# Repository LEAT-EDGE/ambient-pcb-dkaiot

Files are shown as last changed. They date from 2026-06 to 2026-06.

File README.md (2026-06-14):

# Ambient DKAIoT Mainboard PCB

Mainboard PCB for the [Ambient project](https://github.com/LEAT-EDGE/ambient).

<div style="display: flex; justify-content: center; gap: 20px;">
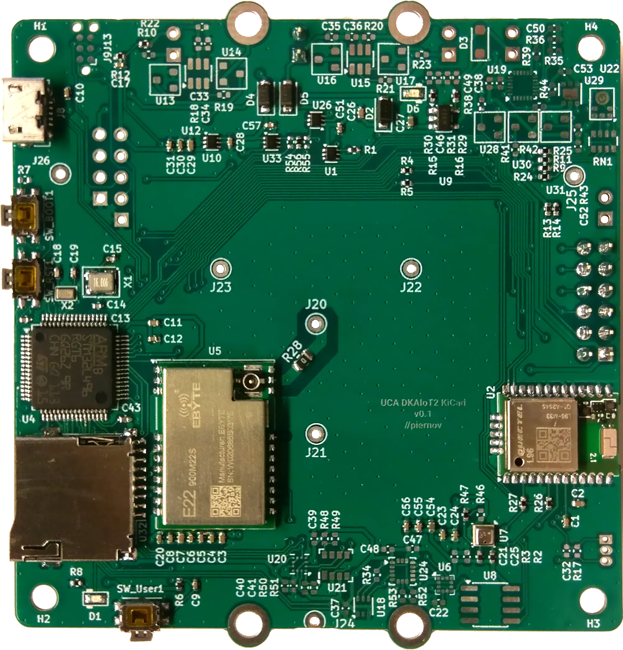
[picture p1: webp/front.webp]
Mainboard front
    
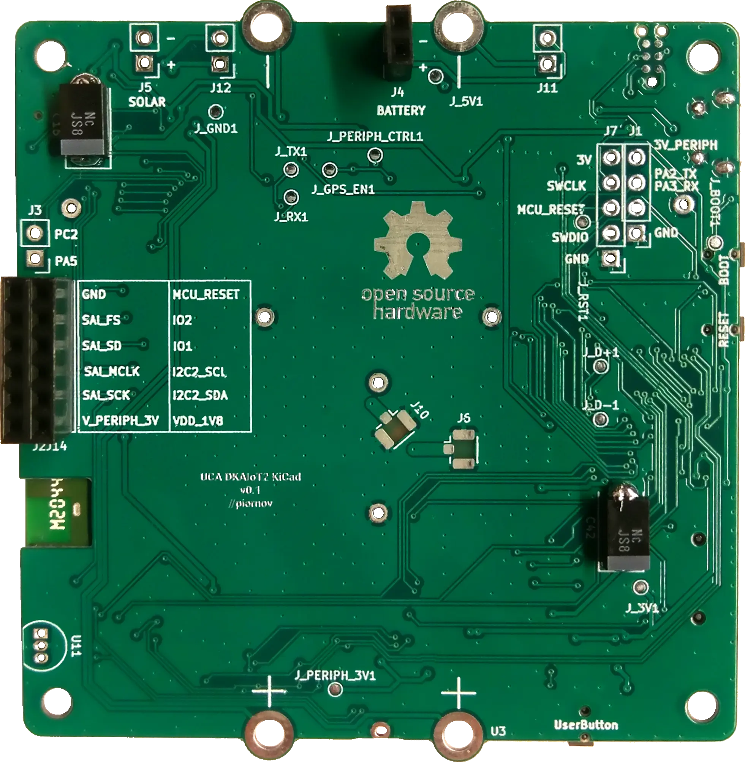
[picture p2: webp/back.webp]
Mainboard back
    
</div>

## Main features

- Microcontroller from the STM32L4 or STM32U5 families (LQFP-64 package, no SMPS)
  - STM32L496RG: low-power, Cortex-M4F 80 MHz, 320 KiB SRAM, 1 MiB Flash
  - STM32U595RI: ultra-low-power, Cortex-M33 160 MHz, 2.5 MiB SRAM, 2 MiB Flash
- LoRa modem (Ebyte E22-900M22S)
- GNSS module (Quectel L96-M33)
- Temperature, humidity and pressure (Bosch BME280)
- Micro-SD card reader

The design also provides empty footprints for several other sensors which are not populated in the Ambient variant:
- Light sensor (LITEON LTR-303ALS-01)
- MEMS microphone (Knowles SPH0645LM4H)
- Indoor air quality (Sensirion SGP30)
- Hall effect (Texas Instruments DRV5023AJQLPG)
- Barometer and altimeter (HopeRF HP203B)
- 3-axis accelerometer, 3-axis gyroscope, 3-axis magnetometer (TDK ICM-20948)
- 3-axis accelerometer, 3-axis magnetometer (STMicroelectronics LSM303AH)
- 3-axis accelerometer (Kionix KX023-1025-FR)
- 3-axis accelerometer (Kionix KXTJ3-1057)

## Project structure
- `/` (repository root): KiCad project
- `gerbers/`: Gerbers generated from the KiCad project
- `libraries/`: KiCad libraries of symbols, footprints and 3D models for components not found in the KiCad official repository
- `pdf/`: Schematics generated from the KiCad project
- `png/`: Screenshots of the KiCad 3D render
- `webp/`: Pictures of the actual board

## Firmware

### Firmware sources

Refer to <https://github.com/LEAT-EDGE/ambient-firmware-zephyr> for the new, Zephyr RTOS-based firmware (compatible with both STM32L4 and STM32U5),
and to <https://github.com/LEAT-EDGE/ambient-firmware-arduino> for the old Arduino-based firmware (not compatible with STM32U5).

### Updating the firmware

In order to flash the firmware, put the microcontroller in bootloader DFU mode by holding the BOOT button (right next to the USB port) and pressing the RESET button (next to the BOOT button), then releasing the BOOT button after a couple of seconds. Alternatively, you can hold the BOOT button while plugging the USB cable in, and releasing it after a couple of seconds.

[dfu-util](https://dfu-util.sourceforge.net/) can then be used to update the firmware.
It is called automatically by the `west flash` command when using the Zephyr-based firmware, or by the Arduino IDE's Upload button when using the Arduino-based firmware.

On Windows, for `dfu-util` to work properly, it is recommended to use the WinUSB driver. [Zadig](https://zadig.akeo.ie/) can be used to change the driver of the `STM32 BOOTLOADER` device to WinUSB.

On Linux, for a standard user to have access to the USB device, you may have to install a [udev rules file](https://github.com/LEAT-EDGE/ambient-firmware-arduino/blob/master/stm32dfu.udev.rules) in `/etc/udev/rules.d/`.

An SWD probe (e.g., STLINK V2 or V3) can also be used through the J7 debug header. Programming and debugging can then be performed using [OpenOCD](https://openocd.org/)

## Connectors and headers

### J1: UART

Exposes the `PA2` and `PA3` pins for the `USART2` peripheral of the microcontroller for debugging purposes.

Pinout:

| Pin | Net |
|---|---|
| **4** | `V_PERIPH_3V` |
| **3** | `PA2_TX` |
| **2** | `PA3_RX` |
| **1** | `GND` |

### J2J14

Main connector for the [audio capture and energy management daughterboard](https://github.com/LEAT-EDGE/ambient-pcb-audiopower).

Exposes the I2S bus (`SAI1B`), an I2C bus (`I2C2`), the 1.8V (`VDD_1V8`) and 3.0V (`V_PERIPH_3V`) peripheral supplies, 2 GPIOs (`PA10`, `PA15`) and the microcontroller reset signal (`MCU_RESET`, for reed switch reset trigger).

Pinout:

| Pin | Net | Pin | Net |
|---|---|---|---|
| **11** | `GND` | **12** | `MCU_RESET` |
| **9**  | `SAI_FS` | **10** | `EXT_MIC_IO_2` |
| **7**  | `SAI_SD` | **8**  | `EXT_MIC_IO_2` |
| **5**  | `SAI_MCLK` | **6**  | `I2C2_SCL` |
| **3**  | `SAI_SCK` | **4**  | `I2C2_SDA` |
| **1**  | `V_PERIPH_3V` | **2**  | `VDD_1V8` |

### J3: ADC/DAC

Unused in the Ambient variant.

Exposes 2 GPIOs (`PA5`, `PC2`) that provides access to the microcontroller's ADC and DAC channels.

Pinout:

| Pin | Net |
|---|---|
| **2** | `PC2_ADC` |
| **1** | `PA5_DAC_ADC` |

### J4: BATTERY

Power input to the board and output of the USB charging circuit.

The [audio capture and energy management daughterboard](https://github.com/LEAT-EDGE/ambient-pcb-audiopower) connects to this header with its J3 connector.

| Pin | Net |
|---|---|
| **2** | `+BATT` |
| **1** | `GND` |

### J5: SOLAR

Unused in the Ambient variant.

Power input to the charging circuit

Pinout:

| Pin | Net |
|---|---|
| **2** | `SOLAR` |
| **1** | `GND` |

### J7: SWD

Exposes the SWD pins of the microcontroller for debugging purposes.

Pinout:

| Pin | Net |
|---|---|
| **5** | `3V` |
| **4** | `SWCLK` |
| **3** | `MCU_RESET` |
| **2** | `SWDIO` |
| **1** | `GND` |

### J11: BATT1

Unused in the Ambient variant.

1st Li-ion cell connector, behind protection circuit.

| Pin | Net |
|---|---|
| **2** | `+BATT1_IN` |
| **1** | `-BATT1_IN` |

### J12: BATT2

Unused in the Ambient variant.

2nd Li-ion cell connector, behind protection circuit.

| Pin | Net |
|---|---|
| **2** | `+BATT2_IN` |
| **1** | `-BATT2_IN` |

### J20/J21/J22/J23: antenna header

Used to attach the [LoRa antenna mezzanine PCB](https://github.com/LEAT-EDGE/ambient-pcb-antenna).

| Pin | Net |
|---|---|
| **J20** | `E22_ANT` |
| **J21** | `GND` |
| **J22** | `GND` |
| **J23** | `GND` |

## Fabrication notes

### PCB

Standard 2-layer 0.8mm stackup:
- 2 layers (front/back),
- 0.8mm thickness,
- 1oz copper,
- FR-4 dielectric,
- HASL finish.

No special requirements, any solder mask and silkscreen color.

Gerbers are provided in the `gerbers/` directory but can be re-generated from the KiCad project.

### Assembly

Recommended automated assembly for top-side only.

Manual assembly for top side:
- J20, J21, J22 and J23 pins (through-hole), to be inserted or cut flush with the back side.

Manual assembly for bottom side:
- C16 and C42 capacitors (SMD),
- J2J14 and J4 connectors (through-hole).

## Testing

Currently, no testing process and firmware is provided. Proper operation of the board can be checked by running the Ambient application firmware.

Short checklist (non exhaustive):
- [ ] USB DFU bootloader detection
- [ ] USB DFU bootloader firmware programming
- [ ] Application firmware boot
- [ ] USB CDC-ACM logs
- [ ] LoRa modem initialization
- [ ] LoRaWAN join
- [ ] LoRaWAN send
- [ ] GNSS time synchronization
- [ ] BME280 temperature read
- [ ] SD card initialization and file write
- [ ] Daughterboard communication:
  - [ ] INA3221 initialization
  - [ ] INA3221 battery/solar current/voltage read
  - [ ] ADC3101 initialization
  - [ ] I2S initialization
  - [ ] I2S audio signal capture

## Acknowledgment

Original circuit design by [@nguyenmanhthao996tn](https://github.com/nguyenmanhthao996tn) in Altium.

The schematics and PCB have been re-designed from scratch in KiCad, while keeping the original circuit ideas, BOM, and component placement to be used as a drop-in replacement.

This project has received funding from [Université Côte d'Azur](https://leat.univ-cotedazur.fr/) and [CERN](https://home.cern/).

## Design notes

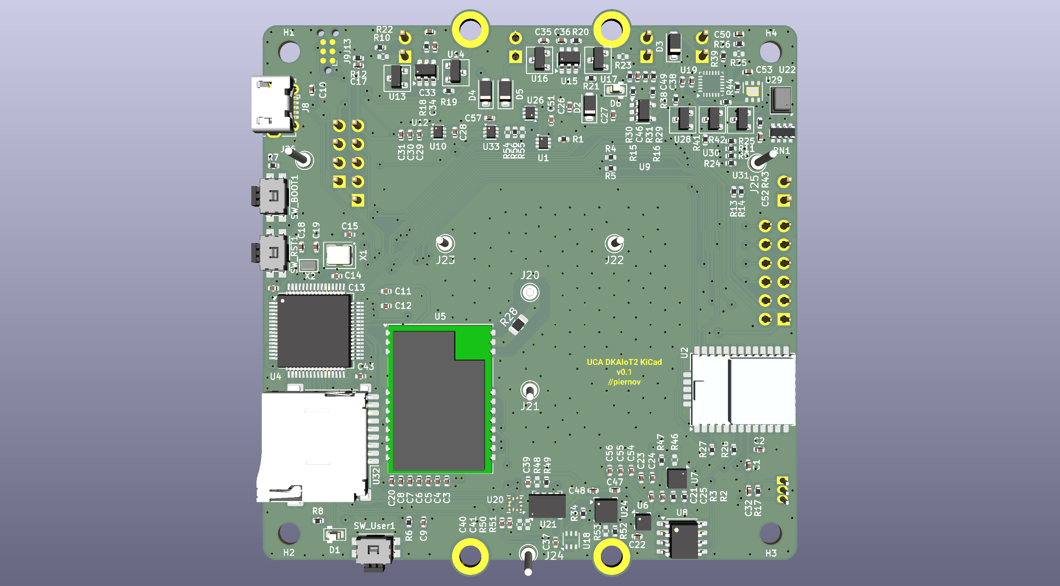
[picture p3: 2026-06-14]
png/uca-dkaiot2-kicad_back.png

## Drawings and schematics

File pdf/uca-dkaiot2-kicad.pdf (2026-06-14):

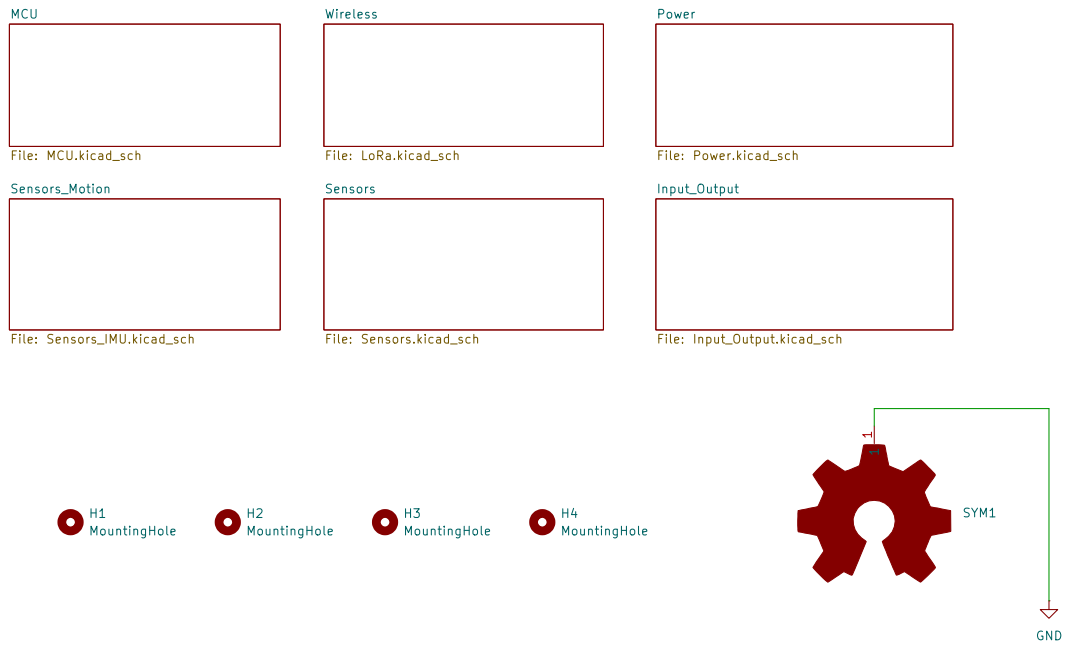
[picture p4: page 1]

Wireless File: LoRa.kicad_sch Sensors File: Sensors.kicad_sch Sensors_Motion

Size: A4 | Rev: v0.2
KiCad E.D.A. 10.0.3 | Id: 1/7

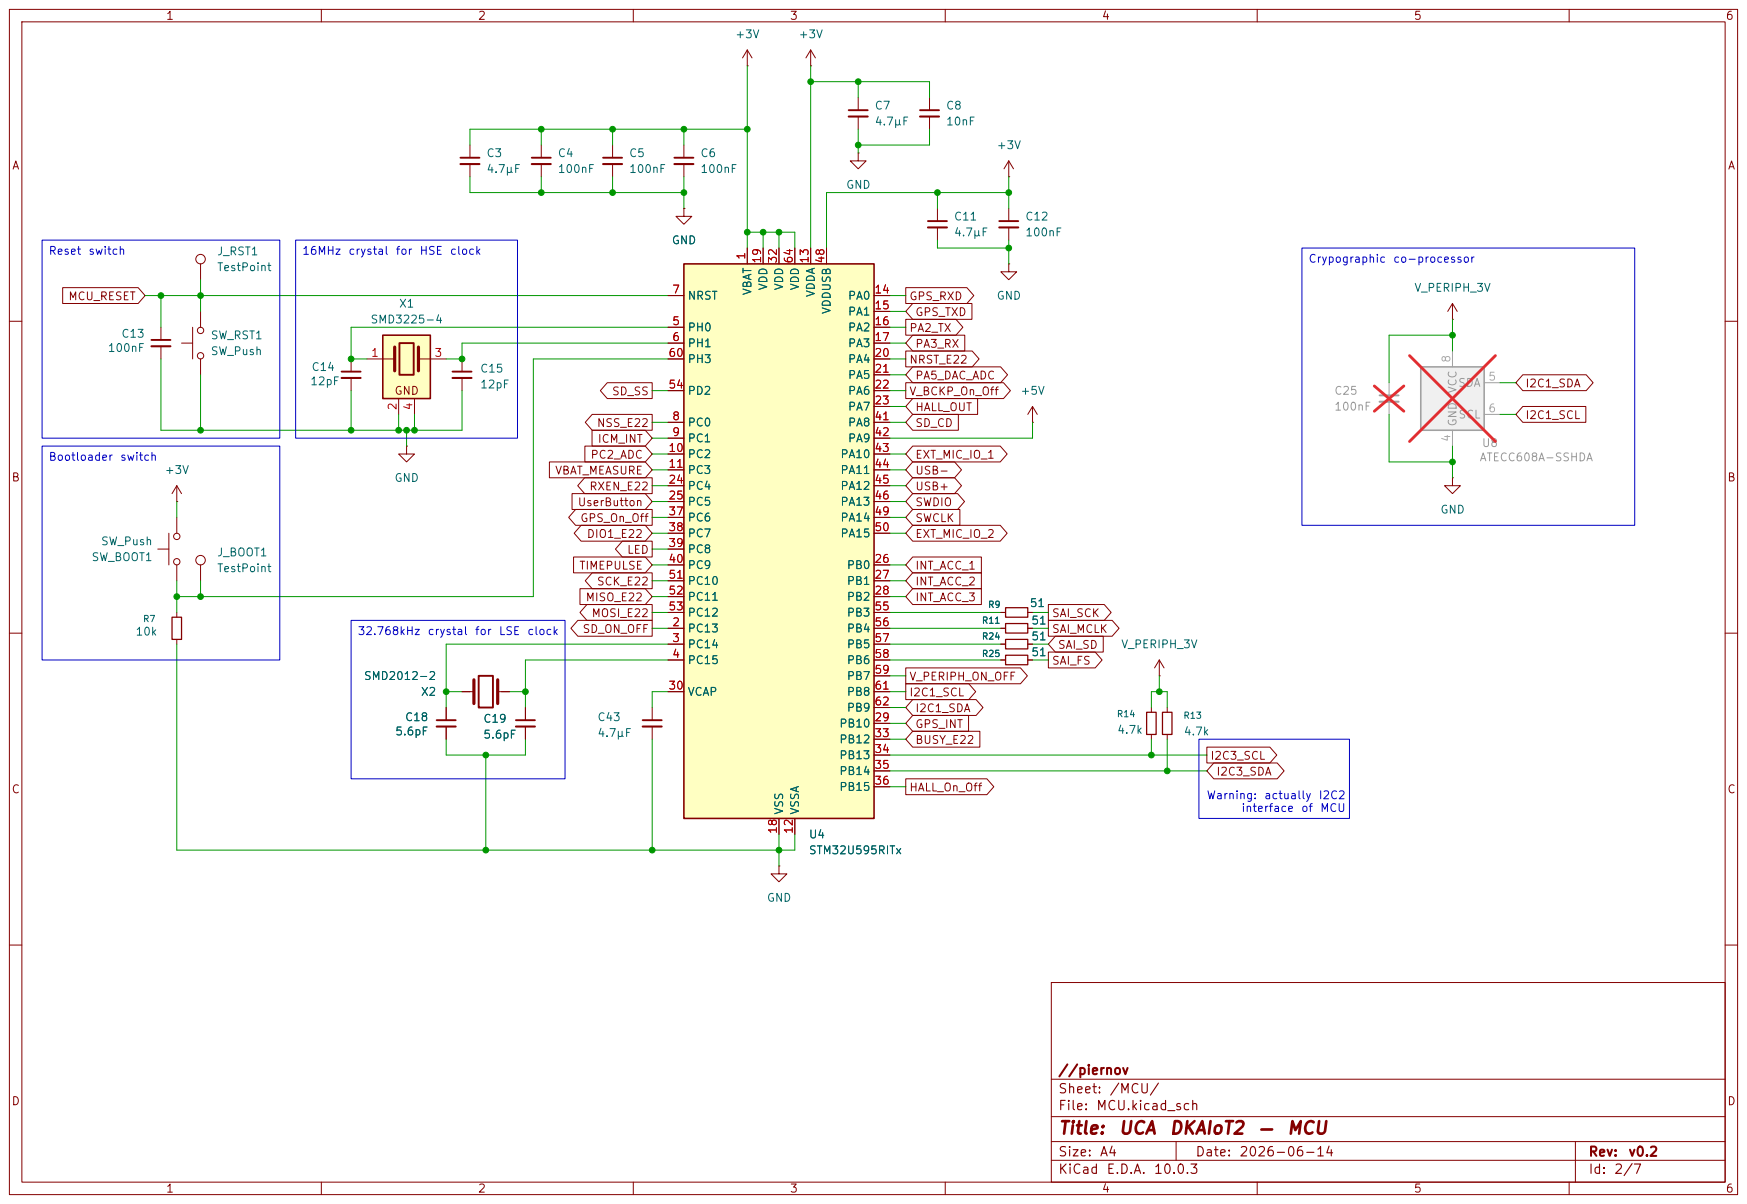
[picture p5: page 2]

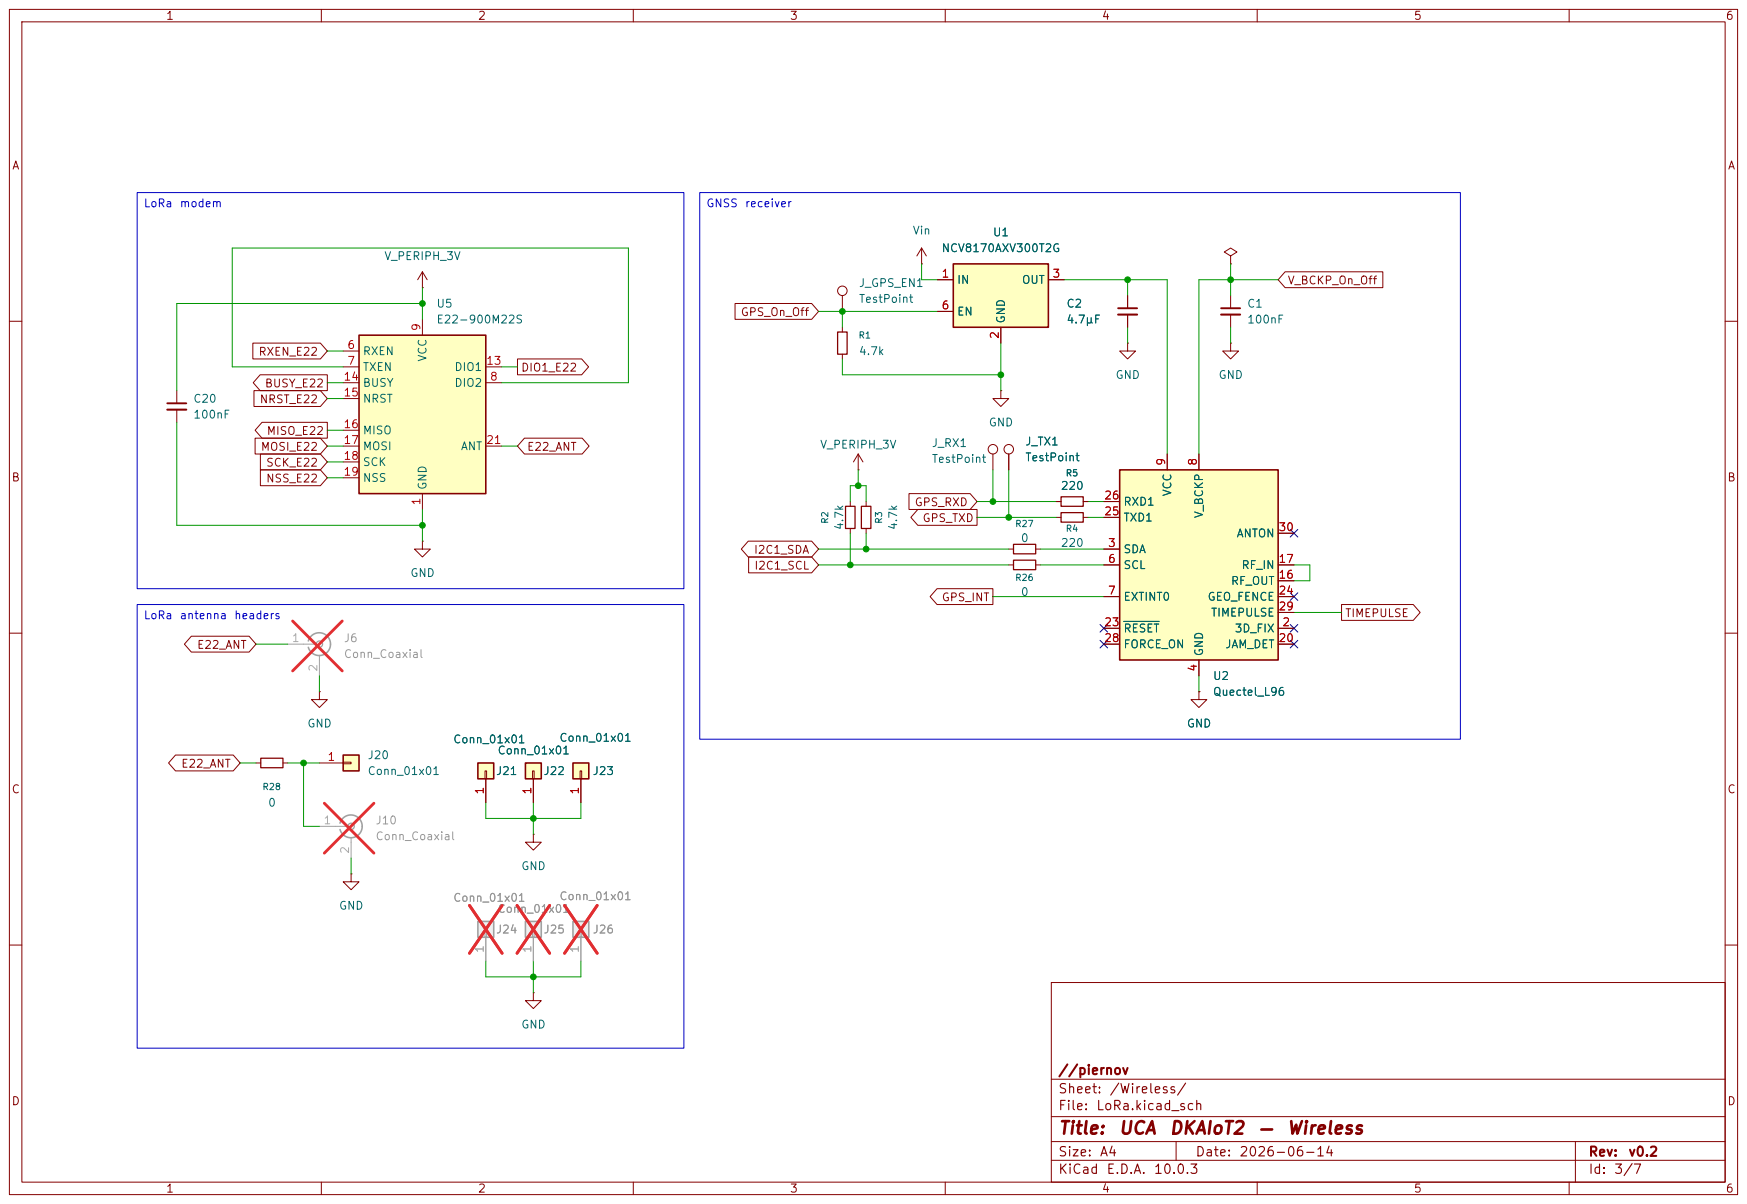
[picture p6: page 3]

9 DIO1 13 BUSY 14 NRST 15 MISO 16 MOSI 17

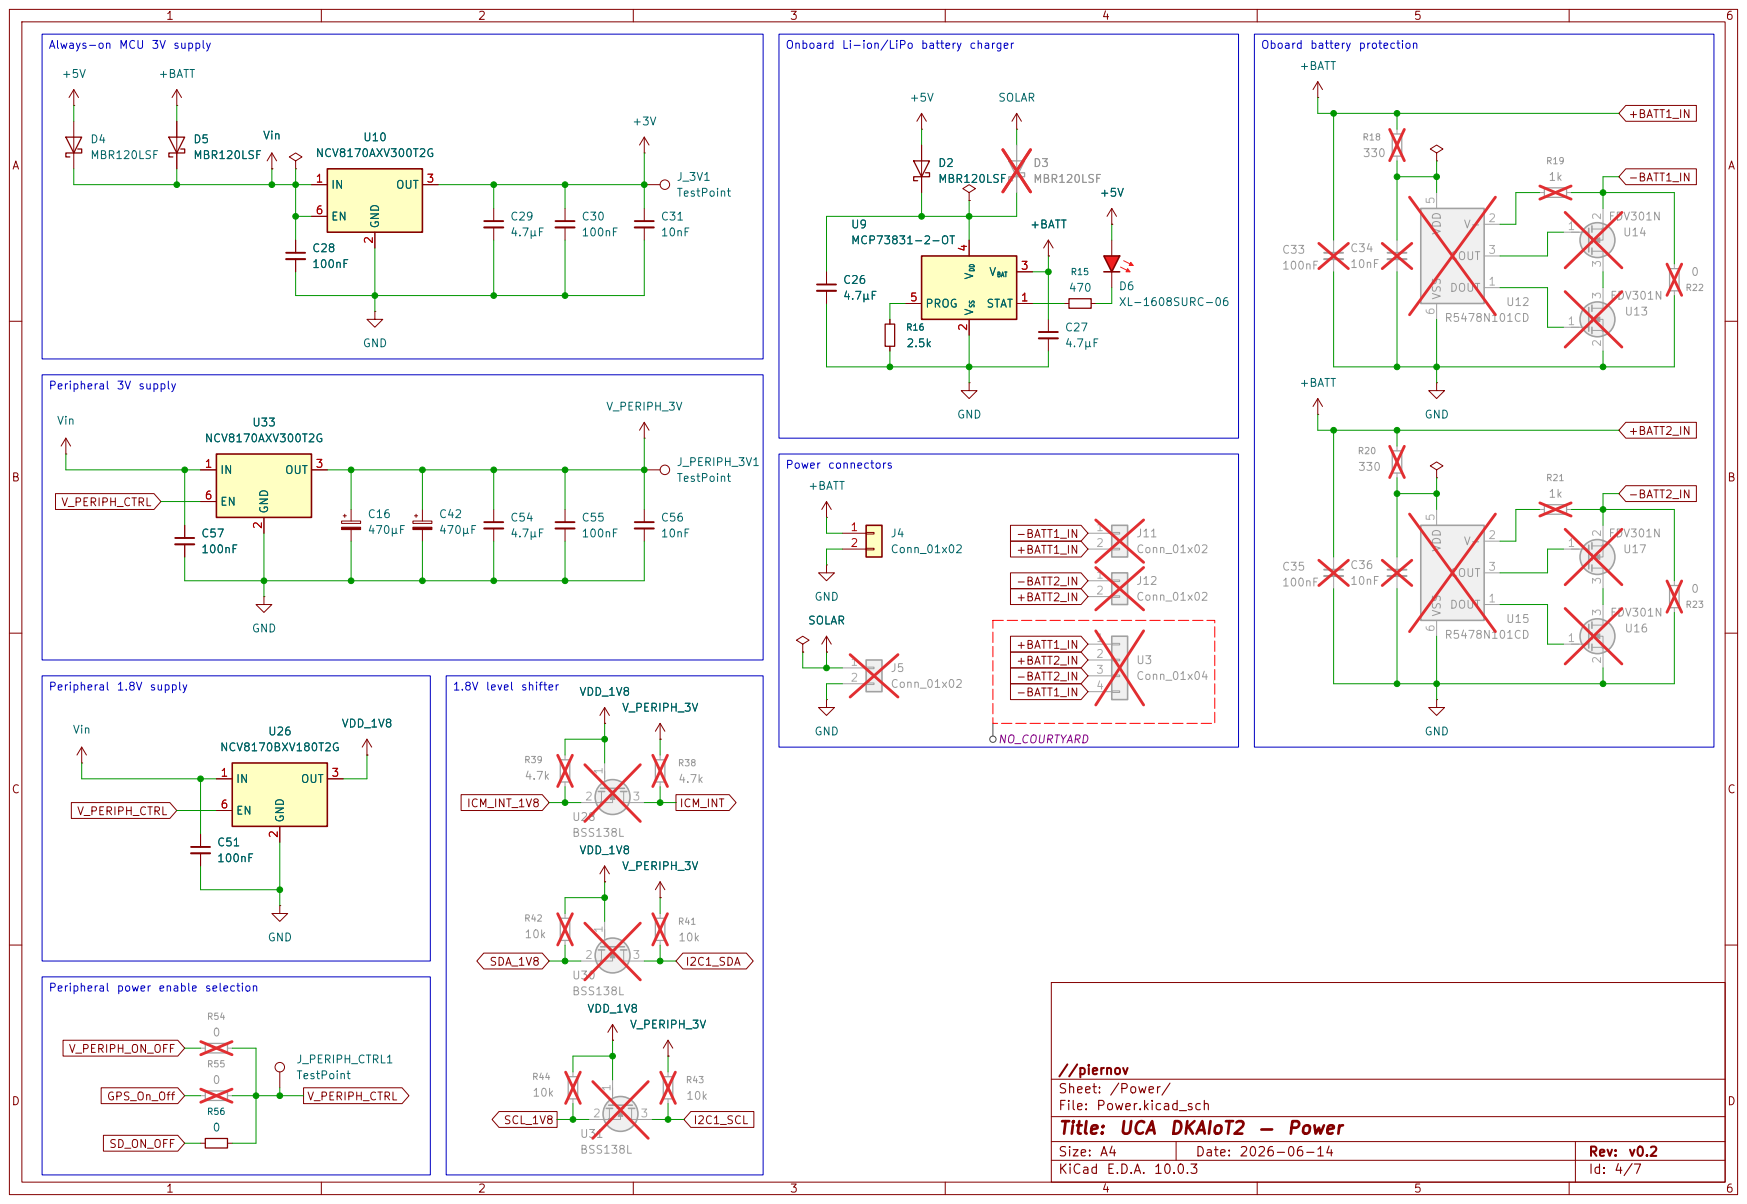
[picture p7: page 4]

Onboard Li-ion/LiPo battery charger

V DD 4 PROG 5 U9MCP73831-2-OT +5V GND

Peripheral power enable selection

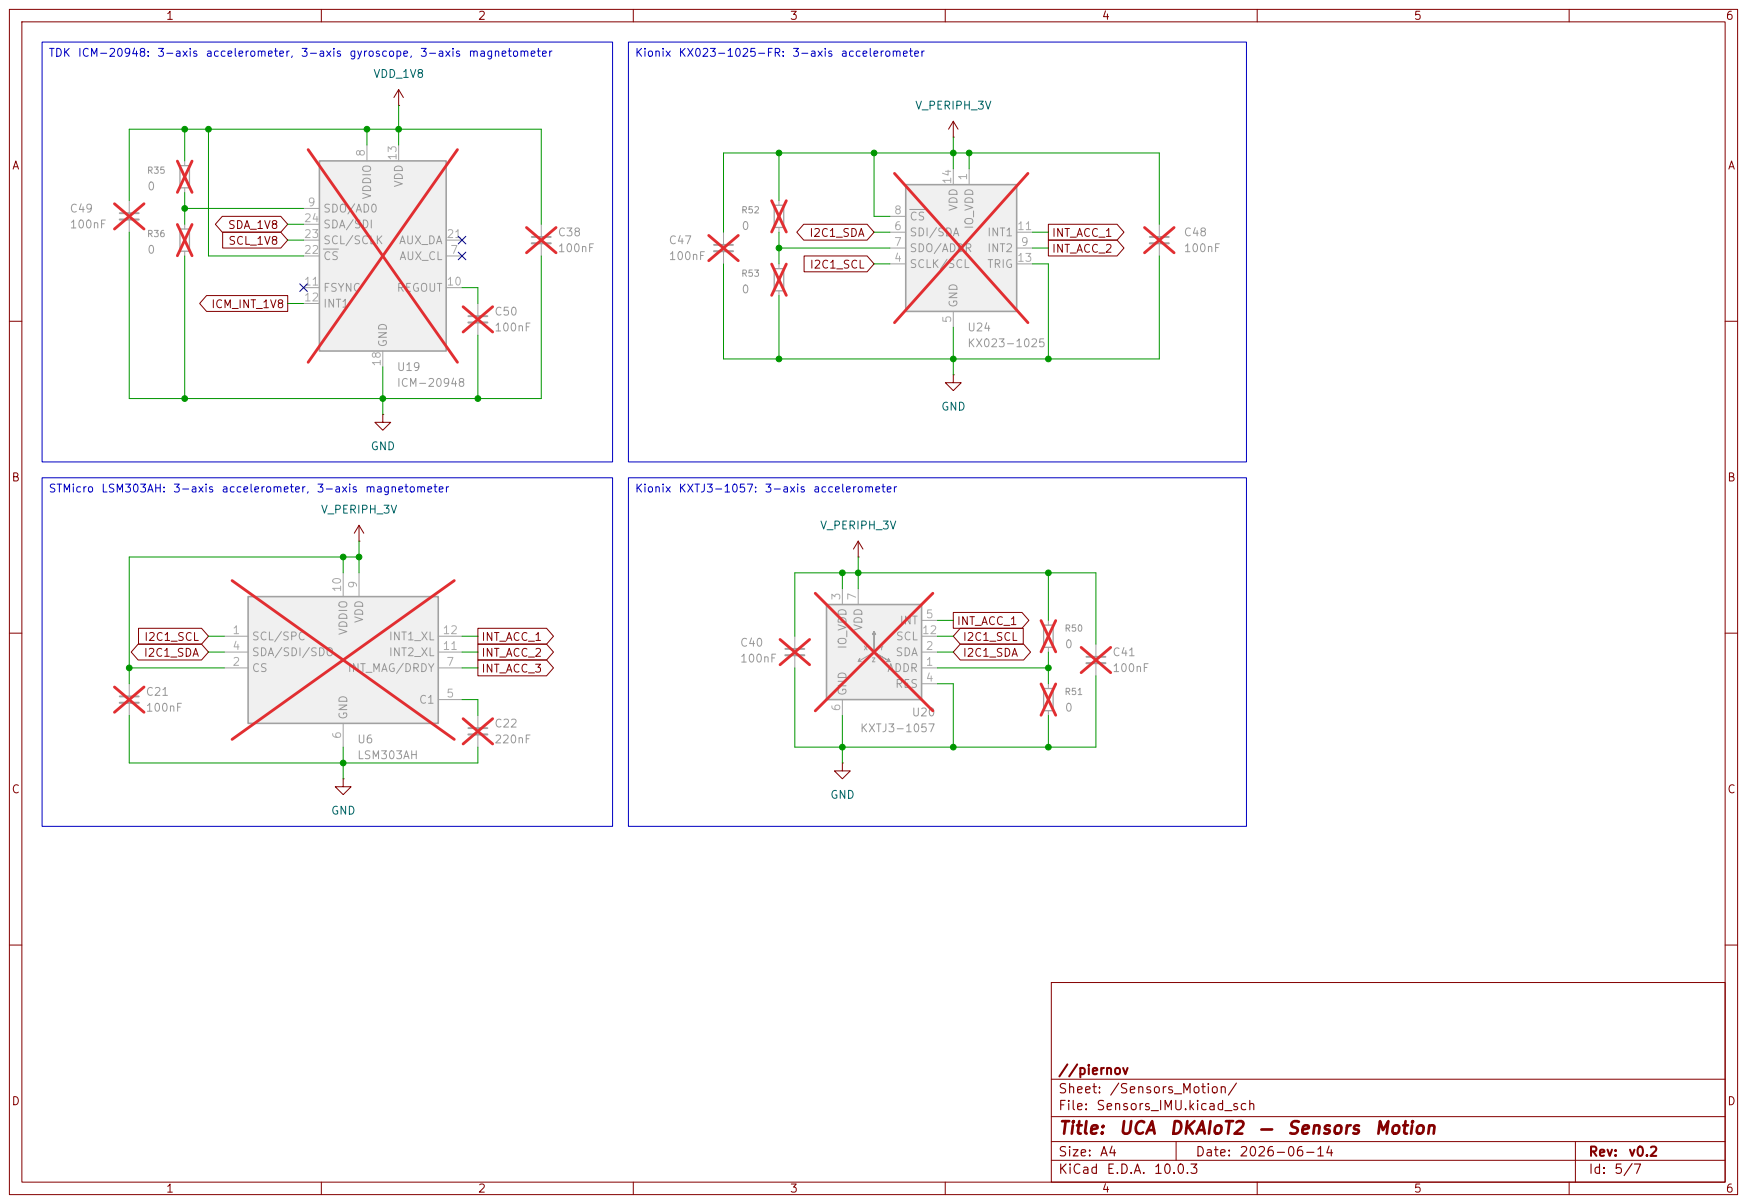
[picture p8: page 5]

Sheet: /Sensors_Motion/
File: Sensors_IMU.kicad_sch
Title: UCA DKAIoT2 — Sensors Motion

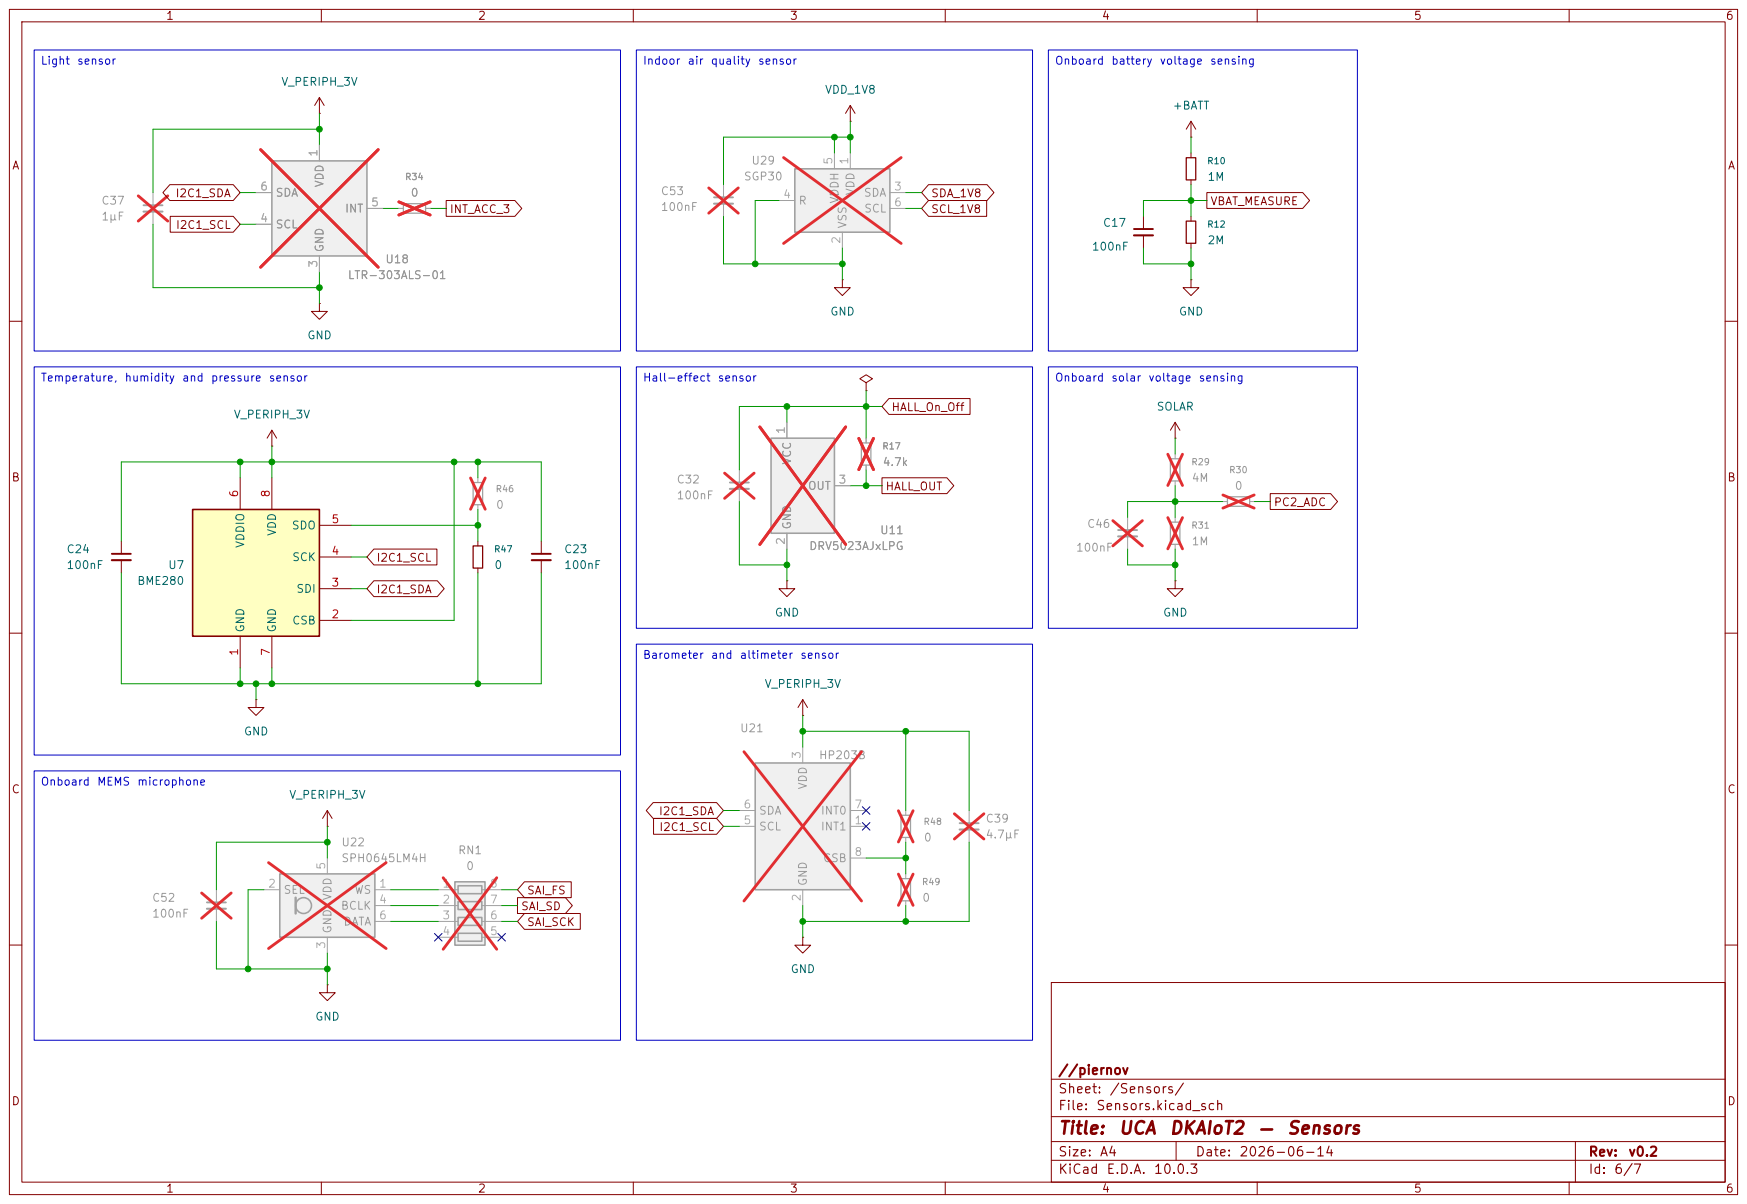
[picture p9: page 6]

Temperature, humidity and pressure sensor

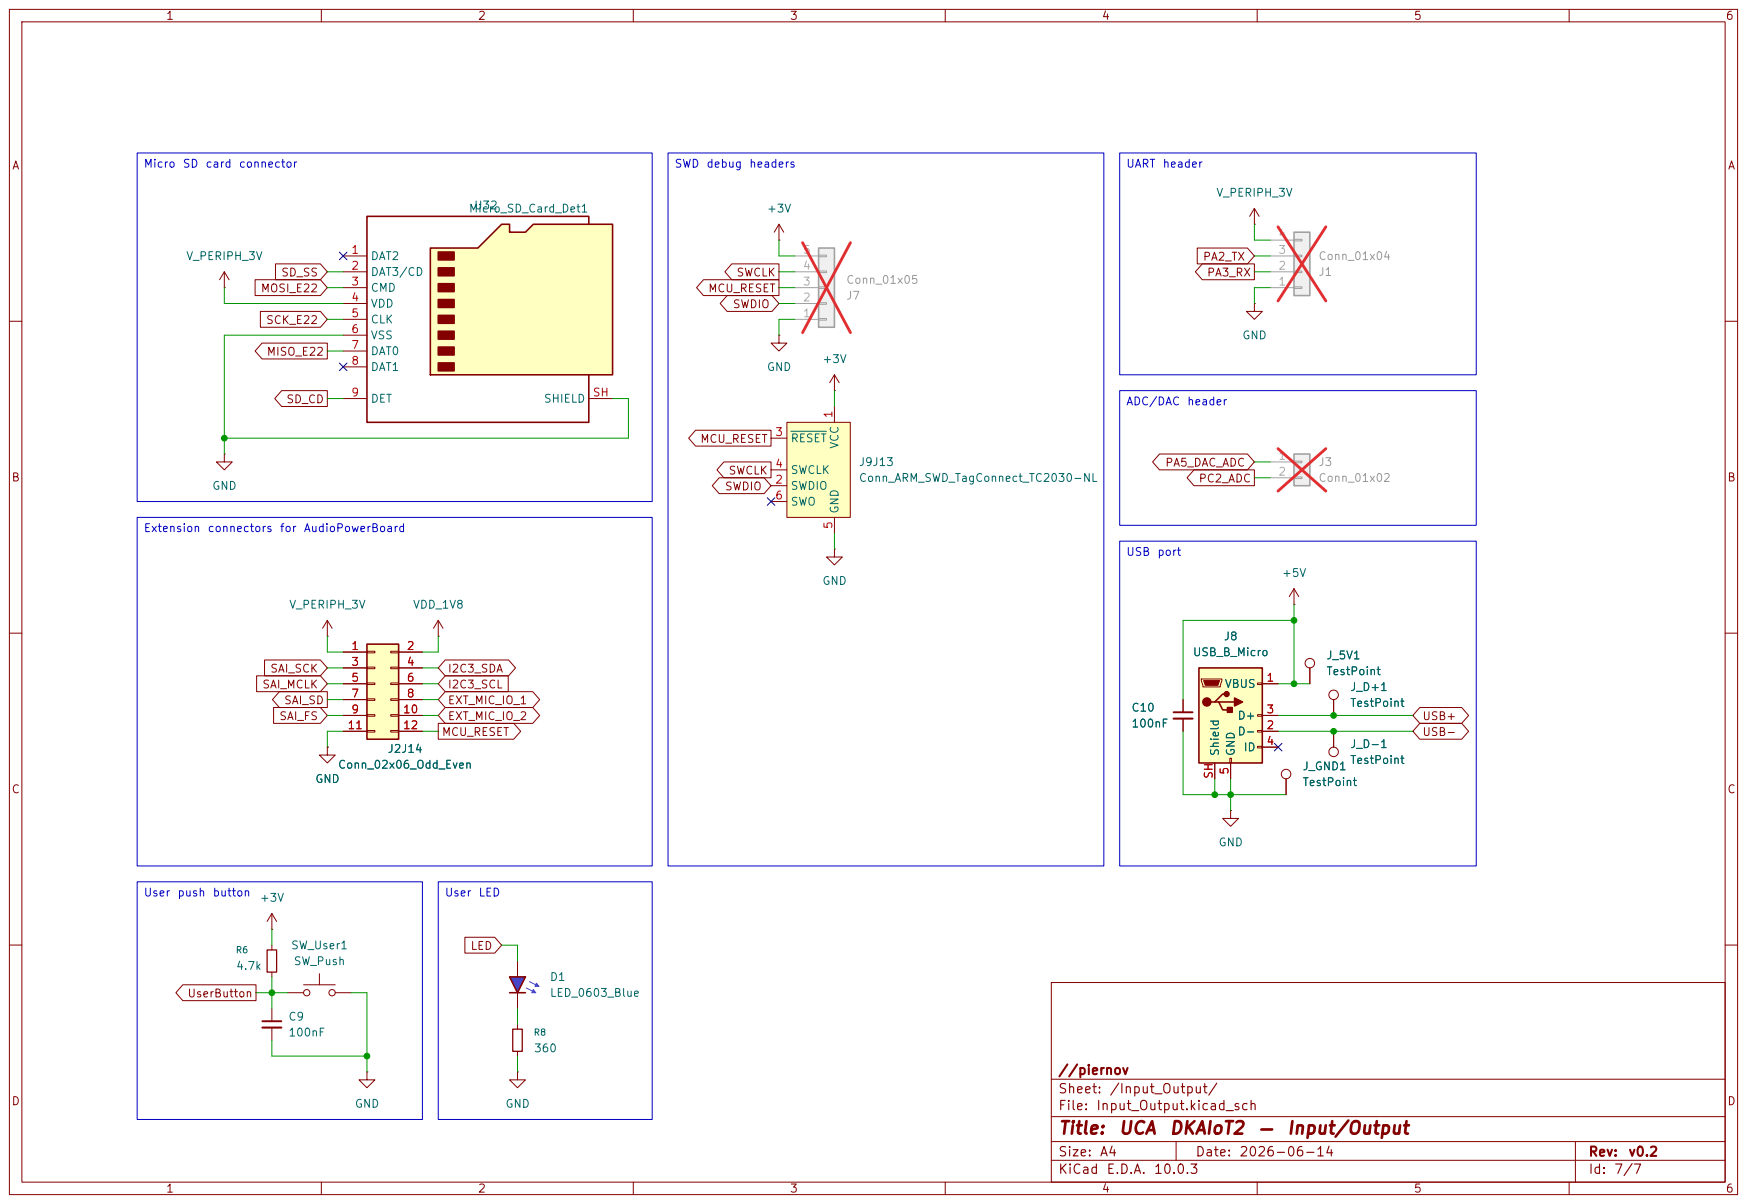
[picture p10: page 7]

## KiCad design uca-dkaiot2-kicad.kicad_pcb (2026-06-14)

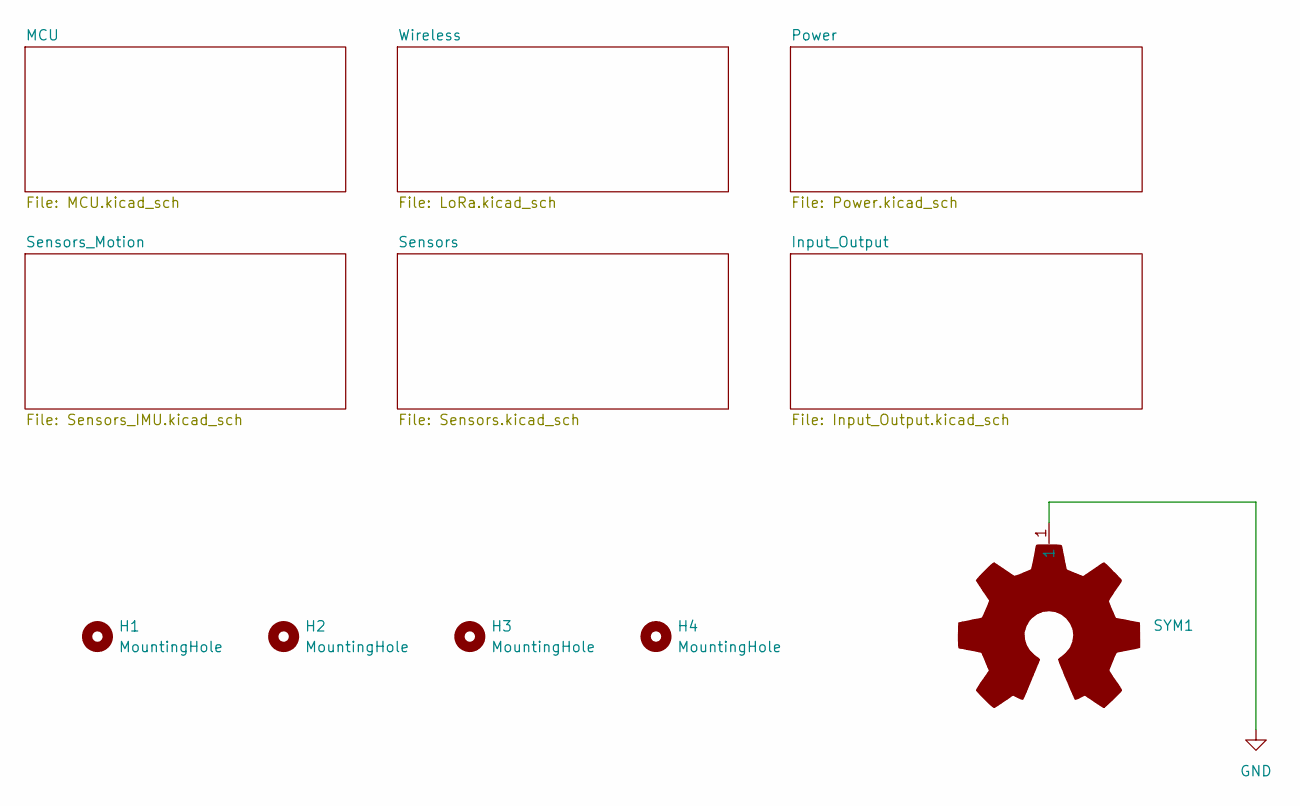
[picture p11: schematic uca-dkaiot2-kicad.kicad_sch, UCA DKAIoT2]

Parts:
H1, H2, H3, H4: MountingHole; MountingHole_3mm
SYM1: Logo_Open_Hardware_Large; OSHW-Logo_11.4x12mm_Copper_SolderMask

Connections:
GND: SYM1.1 (1_1); also elsewhere on the board

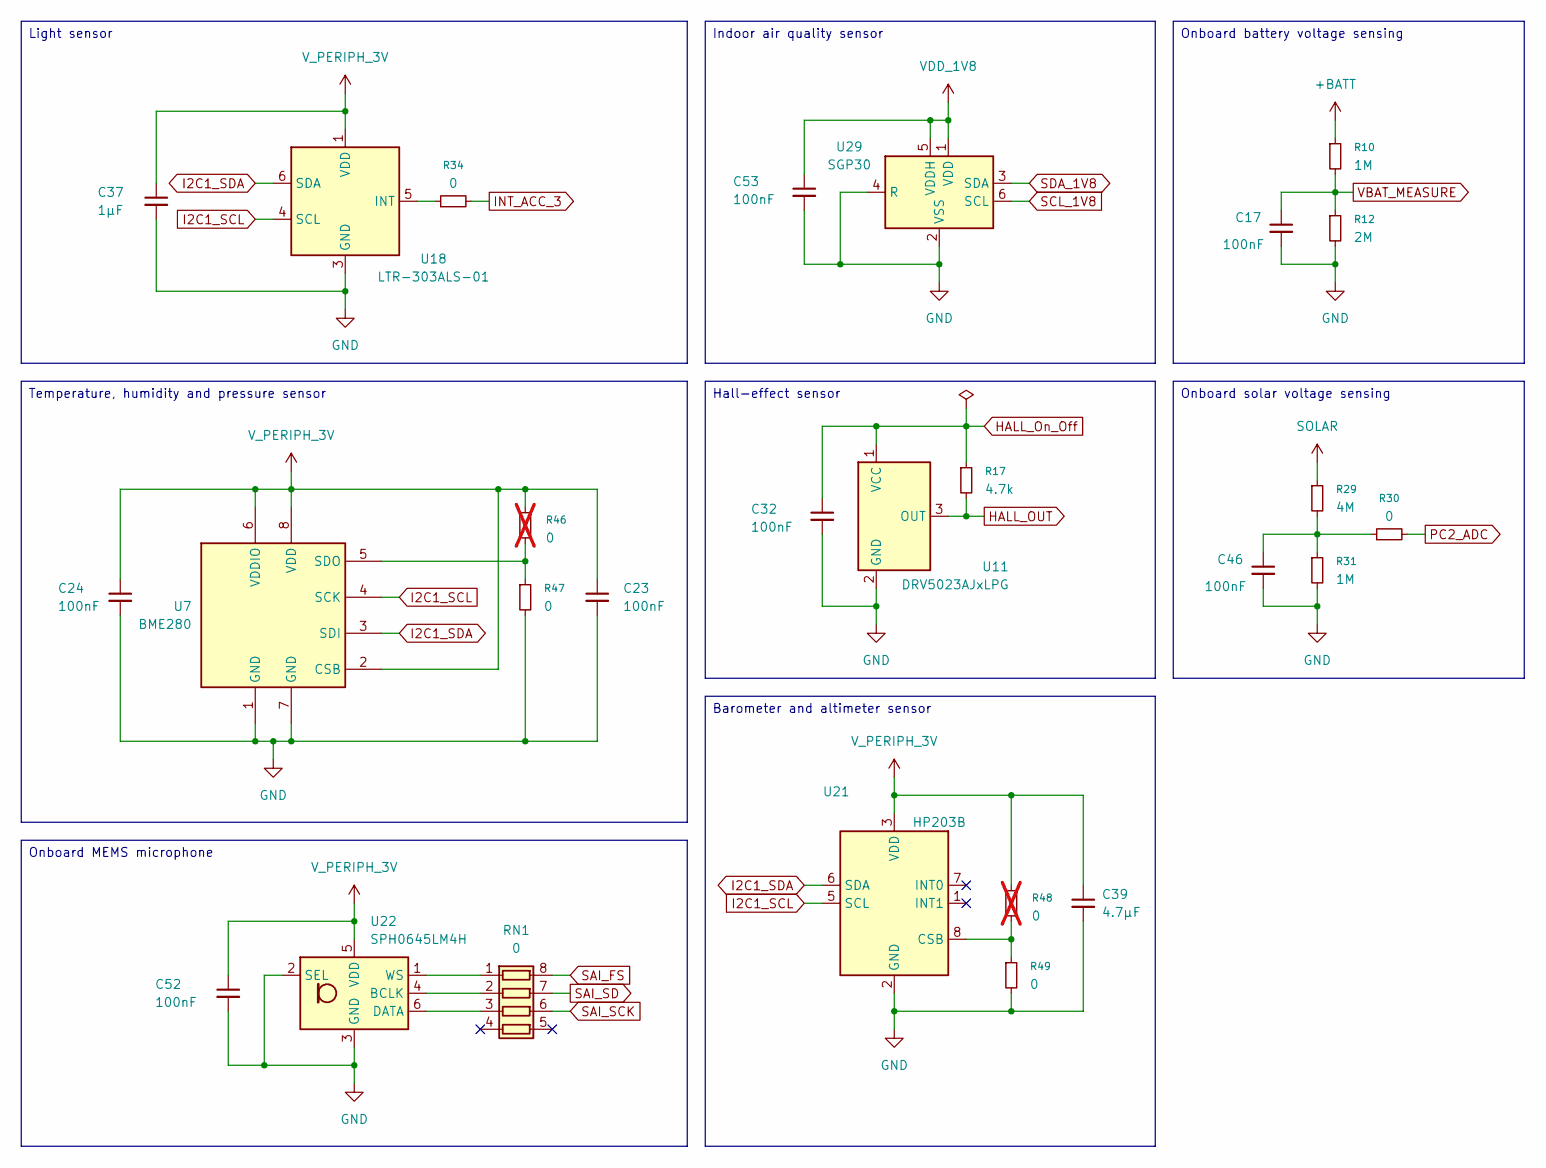
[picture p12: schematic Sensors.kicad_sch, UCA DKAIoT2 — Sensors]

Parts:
C17, C23, C24, C32, C46, C52, C53: 100nF; C_0402_1005Metric
C37: 1µF; C_0402_1005Metric
C39: 4.7µF; C_0402_1005Metric
R10, R31: 1M; R_0402_1005Metric
R12: 2M; R_0402_1005Metric
R17: 4.7k; R_0402_1005Metric
R29: 4M; R_0402_1005Metric
R30, R34, R47, R49: 0; R_0402_1005Metric
R46, R48: 0; R_0402_1005Metric; not fitted
RN1: 0; R_Array_Convex_4x0603
U7: BME280; Bosch_LGA-8_2.5x2.5mm_P0.65mm_ClockwisePinNumbering
U11: DRV5023AJxLPG; TO-92_Inline
U18: LTR-303ALS-01; Lite-On_LTR-303ALS-01
U21: HP203B; LGA-8_3.6x3.8mm_P0.9mm
U22: SPH0645LM4H; Knowles_SPH0645LM4H-6_3.5x2.65mm
U29: SGP30; Sensirion_DFN-6-1EP_2.44x2.44mm_P0.8mm

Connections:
+BATT1_IN: R10.1; also elsewhere on the board
GND: C17.2, C23.2, C24.2, C32.2, C37.2, C39.2, C46.2, C52.2, C53.2, R12.2, R31.2, R47.2, R49.2, U7.1 (GND), U7.7 (GND), U11.2 (GND), U18.3 (GND), U21.2 (GND), U22.2 (SEL), U22.3 (GND), U29.2 (VSS), U29.4 (R), U29.7 (VSS); also elsewhere on the board
HALL_OUT: R17.2, U11.3 (OUT); also elsewhere on the board
HALL_On_Off: C32.1, R17.1, U11.1 (VCC); also elsewhere on the board
I2C1_SCL: U7.4 (SCK), U18.4 (SCL), U21.5 (SCL); also elsewhere on the board
I2C1_SDA: U7.3 (SDI), U18.6 (SDA), U21.6 (SDA); also elsewhere on the board
INT_ACC_3: R34.2; also elsewhere on the board
unnamed: C46.1, R29.2, R30.1, R31.1
unnamed: RN1.1 (R1.1), U22.1 (WS)
unnamed: RN1.2 (R2.1), U22.4 (BCLK)
unnamed: RN1.3 (R3.1), U22.6 (DATA)
unnamed: R46.2, R47.1, U7.5 (SDO)
unnamed: R34.1, U18.5 (INT)
unnamed: R48.2, R49.1, U21.8 (CSB)
PC2_ADC: R30.2; also elsewhere on the board
SAI_FS: RN1.8 (R1.2); also elsewhere on the board
SAI_SCK: RN1.6 (R3.2); also elsewhere on the board
SAI_SD: RN1.7 (R2.2); also elsewhere on the board
SCL_1V8: U29.6 (SCL); also elsewhere on the board
SDA_1V8: U29.3 (SDA); also elsewhere on the board
SOLAR: R29.1; also elsewhere on the board
VBAT_MEASURE: C17.1, R10.2, R12.1; also elsewhere on the board
VDD_1V8: C53.1, U29.1 (VDD), U29.5 (VDDH); also elsewhere on the board
V_PERIPH_3V: C23.1, C24.1, C37.1, C39.1, C52.1, R46.1, R48.1, U7.2 (CSB), U7.6 (VDDIO), U7.8 (VDD), U18.1 (VDD), U21.3 (VDD), U22.5 (VDD); also elsewhere on the board

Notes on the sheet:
Light sensor
Onboard MEMS microphone
Temperature, humidity and pressure sensor
Barometer and altimeter sensor
Indoor air quality sensor
Hall-effect sensor
Onboard battery voltage sensing
Onboard solar voltage sensing

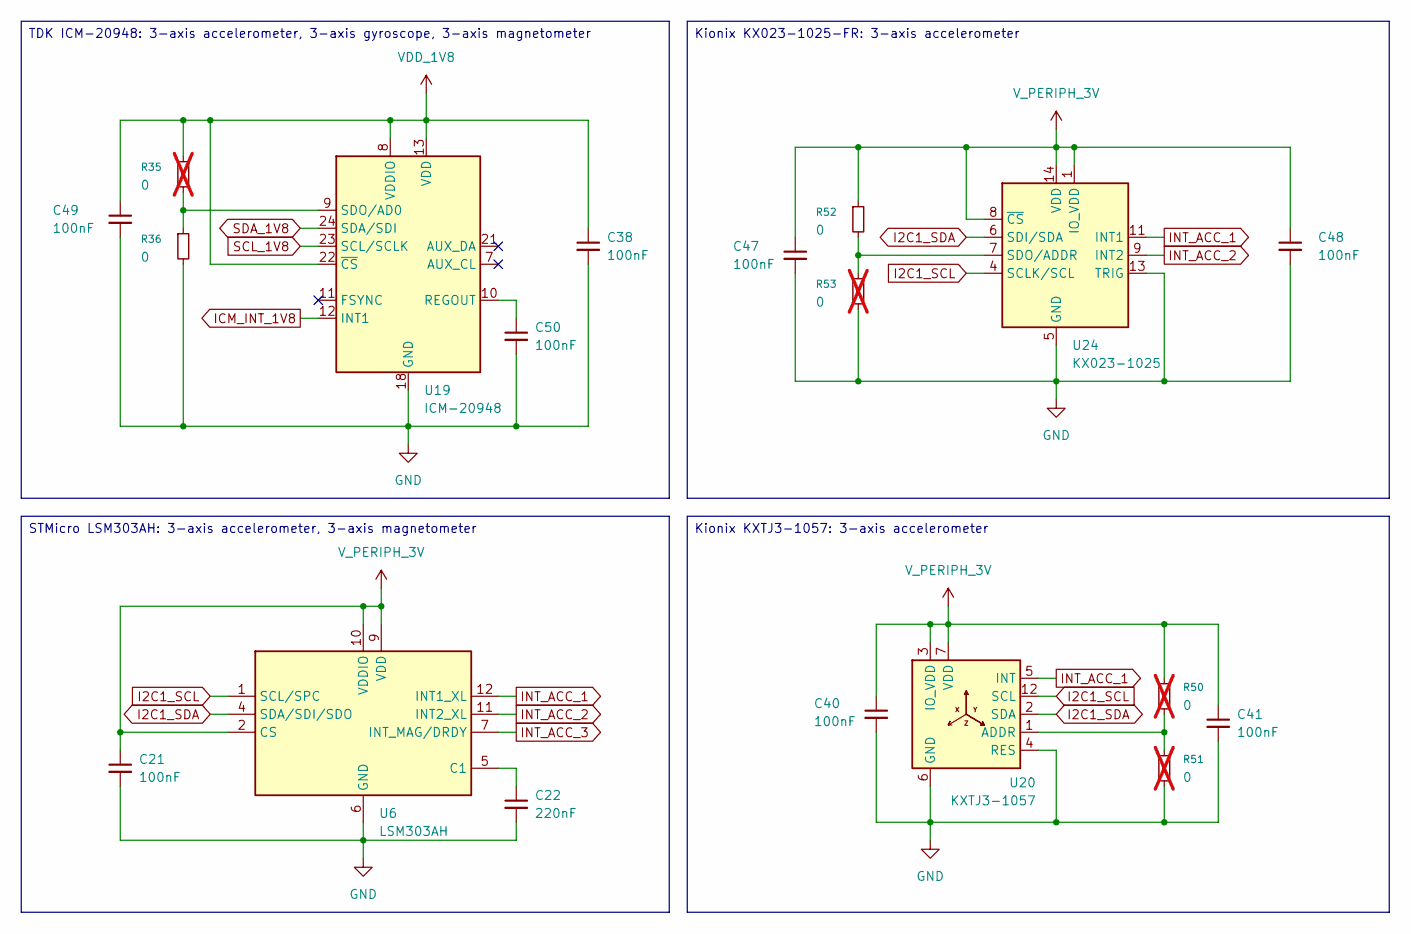
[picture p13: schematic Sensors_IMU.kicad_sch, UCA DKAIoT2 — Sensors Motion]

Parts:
C21, C38, C40, C41, C47, C48, C49, C50: 100nF; C_0402_1005Metric
C22: 220nF; C_0402_1005Metric
R35, R50, R51, R53: 0; R_0402_1005Metric; not fitted
R36, R52: 0; R_0402_1005Metric
U6: LSM303AH; LGA-12_2x2mm_P0.5mm; LCSC C222405
U19: ICM-20948; InvenSense_QFN-24_3x3mm_P0.4mm; LCSC C726001
U20: KXTJ3-1057; Kionix_LGA-12_2x2mm_P0.5mm_LayoutBorder2x4y; LCSC C442603
U24: KX023-1025; LGA-16_3x3mm_P0.5mm_LayoutBorder3x5y

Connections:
GND: C21.2, C22.2, C38.2, C40.2, C41.2, C47.2, C48.2, C49.2, C50.2, R36.2, R51.2, R53.2, U6.3 (RESERVED), U6.6 (GND), U6.8 (GND), U19.18 (GND), U19.20 (GND), U20.4 (RES), U20.6 (GND), U20.8 (GND), U20.9 (GND), U24.5 (GND), U24.12 (GND), U24.13 (TRIG); also elsewhere on the board
I2C1_SCL: U6.1 (SCL/SPC), U20.12 (SCL), U24.4 (SCLK/SCL); also elsewhere on the board
I2C1_SDA: U6.4 (SDA/SDI/SDO), U20.2 (SDA), U24.6 (SDI/SDA); also elsewhere on the board
ICM_INT_1V8: U19.12 (INT1); also elsewhere on the board
INT_ACC_1: U6.12 (INT1_XL), U20.5 (INT), U24.11 (INT1); also elsewhere on the board
INT_ACC_2: U6.11 (INT2_XL), U24.9 (INT2); also elsewhere on the board
INT_ACC_3: U6.7 (INT_MAG/DRDY); also elsewhere on the board
unnamed: C22.1, U6.5 (C1)
unnamed: C50.1, U19.10 (REGOUT)
unnamed: R35.2, R36.1, U19.9 (SDO/AD0)
unnamed: R50.2, R51.1, U20.1 (ADDR)
unnamed: R52.2, R53.1, U24.7 (SDO/ADDR)
SCL_1V8: U19.23 (SCL/SCLK); also elsewhere on the board
SDA_1V8: U19.24 (SDA/SDI); also elsewhere on the board
VDD_1V8: C38.1, C49.1, R35.1, U19.8 (VDDIO), U19.13 (VDD), U19.22 (~CS); also elsewhere on the board
V_PERIPH_3V: C21.1, C40.1, C41.1, C47.1, C48.1, R50.1, R52.1, U6.2 (CS), U6.9 (VDD), U6.10 (VDDIO), U20.3 (IO_VDD), U20.7 (VDD), U20.10 (VDD), U20.11 (IO_VDD), U24.1 (IO_VDD), U24.8 (~CS), U24.14 (VDD); also elsewhere on the board

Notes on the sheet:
TDK ICM-20948: 3-axis accelerometer, 3-axis gyroscope, 3-axis magnetometer
Kionix KX023-1025-FR: 3-axis accelerometer
Kionix KXTJ3-1057: 3-axis accelerometer
STMicro LSM303AH: 3-axis accelerometer, 3-axis magnetometer

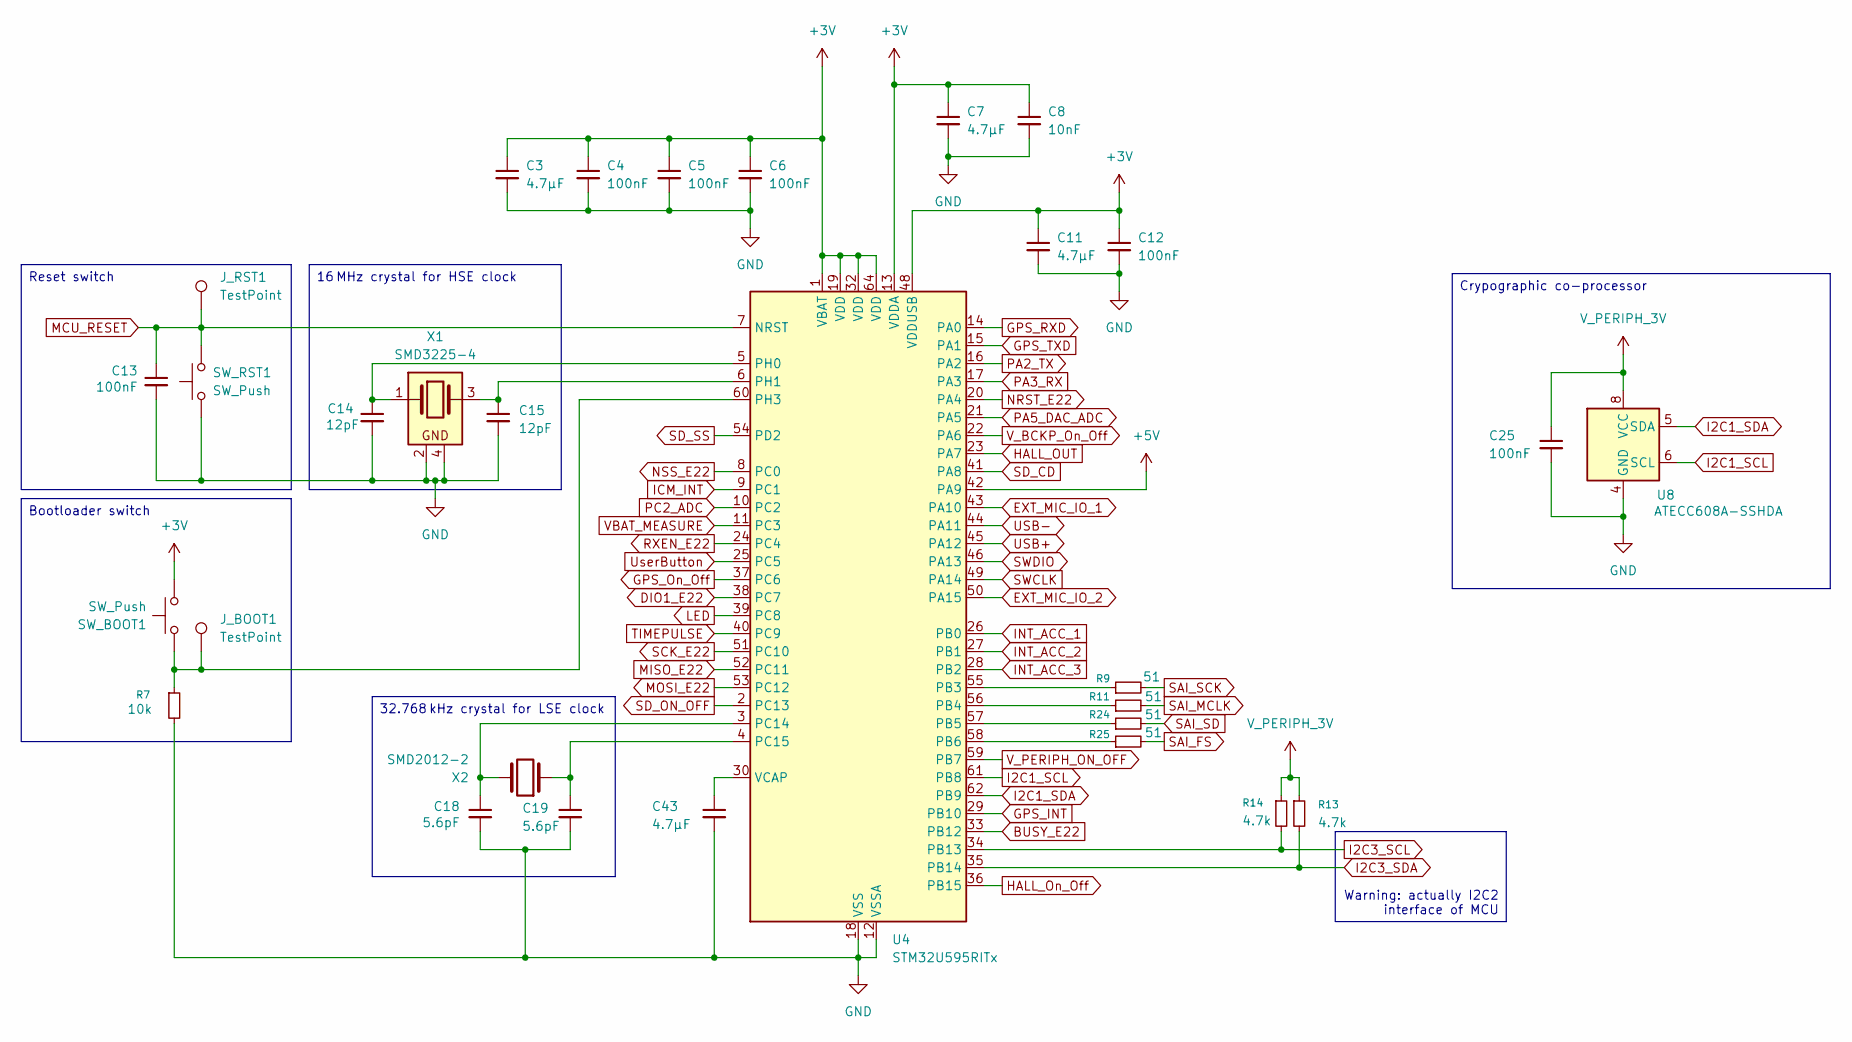
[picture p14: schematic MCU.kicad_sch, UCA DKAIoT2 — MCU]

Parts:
C3, C7, C11, C43: 4.7µF; C_0402_1005Metric
C4, C5, C6, C12, C13, C25: 100nF; C_0402_1005Metric
C8: 10nF; C_0402_1005Metric
C14, C15: 12pF; C_0402_1005Metric
C18, C19: 5.6pF; C_0402_1005Metric
J_BOOT1: TestPoint; TestPoint_Pad_D1.0mm
J_RST1: TestPoint; TestPoint_Pad_D1.0mm
R7: 10k; R_0402_1005Metric
R9, R11, R24, R25: 51; R_0402_1005Metric
R13, R14: 4.7k; R_0402_1005Metric
SW_BOOT1: SW_Push; Panasonic_EVQPUM_EVQPUD
SW_RST1: SW_Push; Panasonic_EVQPUM_EVQPUD
U4: STM32U595RITx; LQFP-64_10x10mm_P0.5mm
U8: ATECC608A-SSHDA; SOIC-8_3.9x4.9mm_P1.27mm
X1: SMD3225-4; Crystal_SMD_3225-4Pin_3.2x2.5mm
X2: SMD2012-2; Crystal_SMD_2012-2Pin_2.0x1.2mm; LCSC C96341

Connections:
+3V: C3.1, C4.1, C5.1, C6.1, C7.1, C8.1, C11.1, C12.1, SW_BOOT1.2, U4.1 (VBAT), U4.13 (VDDA), U4.19 (VDD), U4.32 (VDD), U4.48 (VDDUSB), U4.64 (VDD); also elsewhere on the board
+5V: U4.42 (PA9); also elsewhere on the board
BUSY_E22: U4.33 (PB12); also elsewhere on the board
DIO1_E22: U4.38 (PC7); also elsewhere on the board
EXT_MIC_IO_1: U4.43 (PA10); also elsewhere on the board
EXT_MIC_IO_2: U4.50 (PA15); also elsewhere on the board
GND: C3.2, C4.2, C5.2, C6.2, C7.2, C8.2, C11.2, C12.2, C13.2, C14.2, C15.2, C18.2, C19.2, C25.2, C43.2, R7.2, SW_RST1.1, U4.12 (VSSA), U4.18 (VSS), U4.31 (VSS), U4.47 (VSS), U4.63 (VSS), U8.4 (GND), X1.2, X1.4; also elsewhere on the board
GPS_INT: U4.29 (PB10); also elsewhere on the board
GPS_On_Off: U4.37 (PC6); also elsewhere on the board
GPS_RXD: U4.14 (PA0); also elsewhere on the board
GPS_TXD: U4.15 (PA1); also elsewhere on the board
HALL_OUT: U4.23 (PA7); also elsewhere on the board
HALL_On_Off: U4.36 (PB15); also elsewhere on the board
I2C1_SCL: U4.61 (PB8), U8.6 (SCL); also elsewhere on the board
I2C1_SDA: U4.62 (PB9), U8.5 (SDA); also elsewhere on the board
I2C3_SCL: R14.2, U4.34 (PB13); also elsewhere on the board
I2C3_SDA: R13.2, U4.35 (PB14); also elsewhere on the board
ICM_INT: U4.9 (PC1); also elsewhere on the board
INT_ACC_1: U4.26 (PB0); also elsewhere on the board
INT_ACC_2: U4.27 (PB1); also elsewhere on the board
INT_ACC_3: U4.28 (PB2); also elsewhere on the board
LED: U4.39 (PC8); also elsewhere on the board
MCU_RESET: C13.1, J_RST1.1 (1_1), SW_RST1.2, U4.7 (NRST); also elsewhere on the board
MISO_E22: U4.52 (PC11); also elsewhere on the board
MOSI_E22: U4.53 (PC12); also elsewhere on the board
NRST_E22: U4.20 (PA4); also elsewhere on the board
NSS_E22: U4.8 (PC0); also elsewhere on the board
unnamed: R9.1, U4.55 (PB3)
unnamed: R11.1, U4.56 (PB4)
unnamed: R24.1, U4.57 (PB5)
unnamed: R25.1, U4.58 (PB6)
unnamed: C18.1, U4.3 (PC14), X2.2
unnamed: C19.1, U4.4 (PC15), X2.1
unnamed: C14.1, U4.5 (PH0), X1.1
unnamed: C15.1, U4.6 (PH1), X1.3
unnamed: J_BOOT1.1 (1_1), R7.1, SW_BOOT1.1, U4.60 (PH3)
unnamed: C43.1, U4.30 (VCAP)
PA2_TX: U4.16 (PA2); also elsewhere on the board
PA3_RX: U4.17 (PA3); also elsewhere on the board
PA5_DAC_ADC: U4.21 (PA5); also elsewhere on the board
PC2_ADC: U4.10 (PC2); also elsewhere on the board
RXEN_E22: U4.24 (PC4); also elsewhere on the board
SAI_FS: R25.2; also elsewhere on the board
SAI_MCLK: R11.2; also elsewhere on the board
SAI_SCK: R9.2; also elsewhere on the board
SAI_SD: R24.2; also elsewhere on the board
SCK_E22: U4.51 (PC10); also elsewhere on the board
SD_CD: U4.41 (PA8); also elsewhere on the board
SD_ON_OFF: U4.2 (PC13); also elsewhere on the board
SD_SS: U4.54 (PD2); also elsewhere on the board
SWCLK: U4.49 (PA14); also elsewhere on the board
SWDIO: U4.46 (PA13); also elsewhere on the board
TIMEPULSE: U4.40 (PC9); also elsewhere on the board
USB+: U4.45 (PA12); also elsewhere on the board
USB-: U4.44 (PA11); also elsewhere on the board
UserButton: U4.25 (PC5); also elsewhere on the board
VBAT_MEASURE: U4.11 (PC3); also elsewhere on the board
V_BCKP_On_Off: U4.22 (PA6); also elsewhere on the board
V_PERIPH_3V: C25.1, R13.1, R14.1, U8.8 (VCC); also elsewhere on the board
V_PERIPH_ON_OFF: U4.59 (PB7); also elsewhere on the board

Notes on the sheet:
16 MHz crystal for HSE clock
Warning: actually I2C2 interface of MCU
32.768 kHz crystal for LSE clock
Bootloader switch
Crypographic co-processor
Reset switch

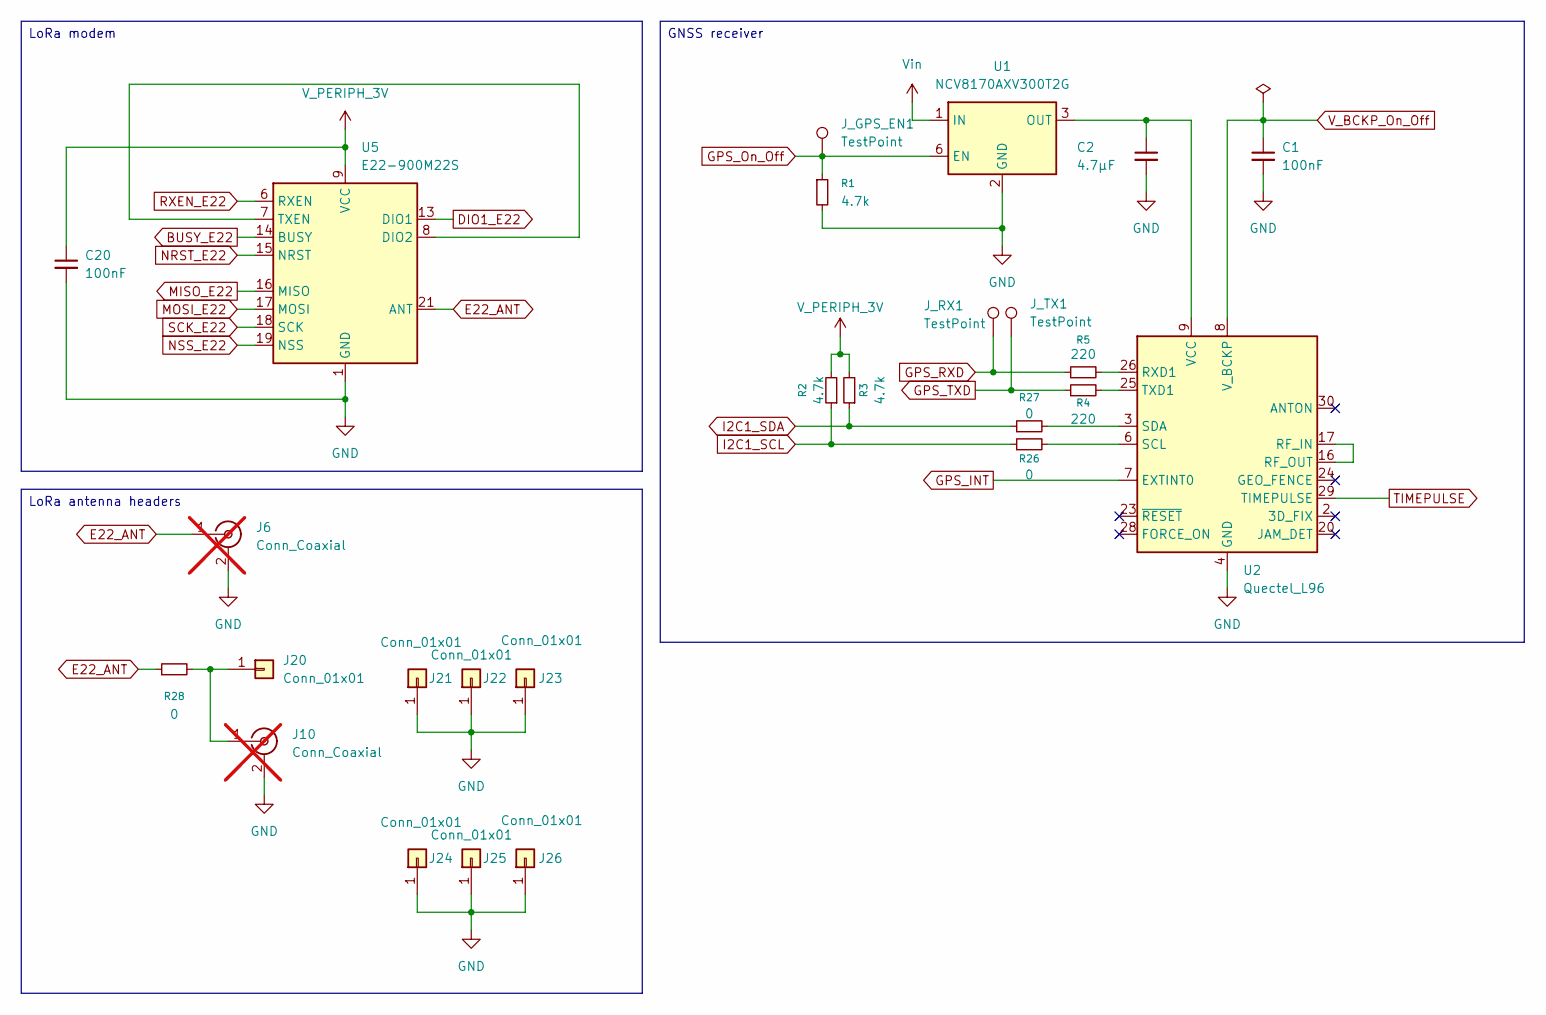
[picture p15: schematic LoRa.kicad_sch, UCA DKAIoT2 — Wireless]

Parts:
C1, C20: 100nF; C_0402_1005Metric
C2: 4.7µF; C_0402_1005Metric
J6, J10: Conn_Coaxial; U.FL_Hirose_U.FL-R-SMT-1_Vertical; not fitted
J20, J21, J22, J23, J24, J25, J26: Conn_01x01; Pin_D1.0mm_L10.0mm
J_GPS_EN1: TestPoint; TestPoint_Pad_D1.0mm
J_RX1: TestPoint; TestPoint_Pad_D1.0mm
J_TX1: TestPoint; TestPoint_Pad_D1.0mm
R1, R2, R3: 4.7k; R_0402_1005Metric
R4, R5: 220; R_0402_1005Metric
R26, R27: 0; R_0402_1005Metric
R28: 0; R_0805_2012Metric
U1: NCV8170AXV300T2G; SOT-563
U2: Quectel_L96; LCSC C5197298
U5: E22-900M22S; E22-400M22S; LCSC C411293

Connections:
BUSY_E22: U5.14 (BUSY); also elsewhere on the board
DIO1_E22: U5.13 (DIO1); also elsewhere on the board
E22_ANT: J6.1 (In), R28.1, U5.21 (ANT)
GND: C1.2, C2.2, C20.2, J6.2 (Ext), J10.2 (Ext), J21.1 (Pin_1_1), J22.1 (Pin_1_1), J23.1 (Pin_1_1), J24.1 (Pin_1_1), J25.1 (Pin_1_1), J26.1 (Pin_1_1), R1.2, U1.2 (GND), U1.5 (GND), U2.4 (GND), U2.5 (GND), U2.10 (GND), U2.11 (GND), U2.12 (GND), U2.13 (GND), U2.14 (GND), U2.15 (GND), U2.18 (GND), U2.19 (GND), U2.21 (GND), U2.22 (GND), U2.27 (GND), U2.31 (GND), U5.1 (GND), U5.2 (GND), U5.3 (GND), U5.4 (GND), U5.5 (GND), U5.10 (GND), U5.11 (GND), U5.12 (GND), U5.20 (GND), U5.22 (GND); also elsewhere on the board
GPS_INT: U2.7 (EXTINT0); also elsewhere on the board
GPS_On_Off: J_GPS_EN1.1 (1_1), R1.1, U1.6 (EN); also elsewhere on the board
GPS_RXD: J_RX1.1 (1_1), R5.1; also elsewhere on the board
GPS_TXD: J_TX1.1 (1_1), R4.1; also elsewhere on the board
I2C1_SCL: R2.1, R26.1; also elsewhere on the board
I2C1_SDA: R3.1, R27.1; also elsewhere on the board
MISO_E22: U5.16 (MISO); also elsewhere on the board
MOSI_E22: U5.17 (MOSI); also elsewhere on the board
NRST_E22: U5.15 (NRST); also elsewhere on the board
NSS_E22: U5.19 (NSS); also elsewhere on the board
unnamed: J10.1 (In), J20.1 (Pin_1_1), R28.2
unnamed: C2.1, U1.3 (OUT), U2.9 (VCC)
unnamed: U2.16 (RF_OUT), U2.17 (RF_IN)
unnamed: R5.2, U2.26 (RXD1)
unnamed: R26.2, U2.6 (SCL)
unnamed: R27.2, U2.3 (SDA)
unnamed: R4.2, U2.25 (TXD1)
unnamed: U5.7 (TXEN), U5.8 (DIO2)
RXEN_E22: U5.6 (RXEN); also elsewhere on the board
SCK_E22: U5.18 (SCK); also elsewhere on the board
TIMEPULSE: U2.29 (TIMEPULSE); also elsewhere on the board
V_BCKP_On_Off: C1.1, U2.8 (V_BCKP); also elsewhere on the board
V_PERIPH_3V: C20.1, R2.2, R3.2, U5.9 (VCC); also elsewhere on the board
Vin: U1.1 (IN); also elsewhere on the board

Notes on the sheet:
GNSS receiver
LoRa antenna headers
LoRa modem

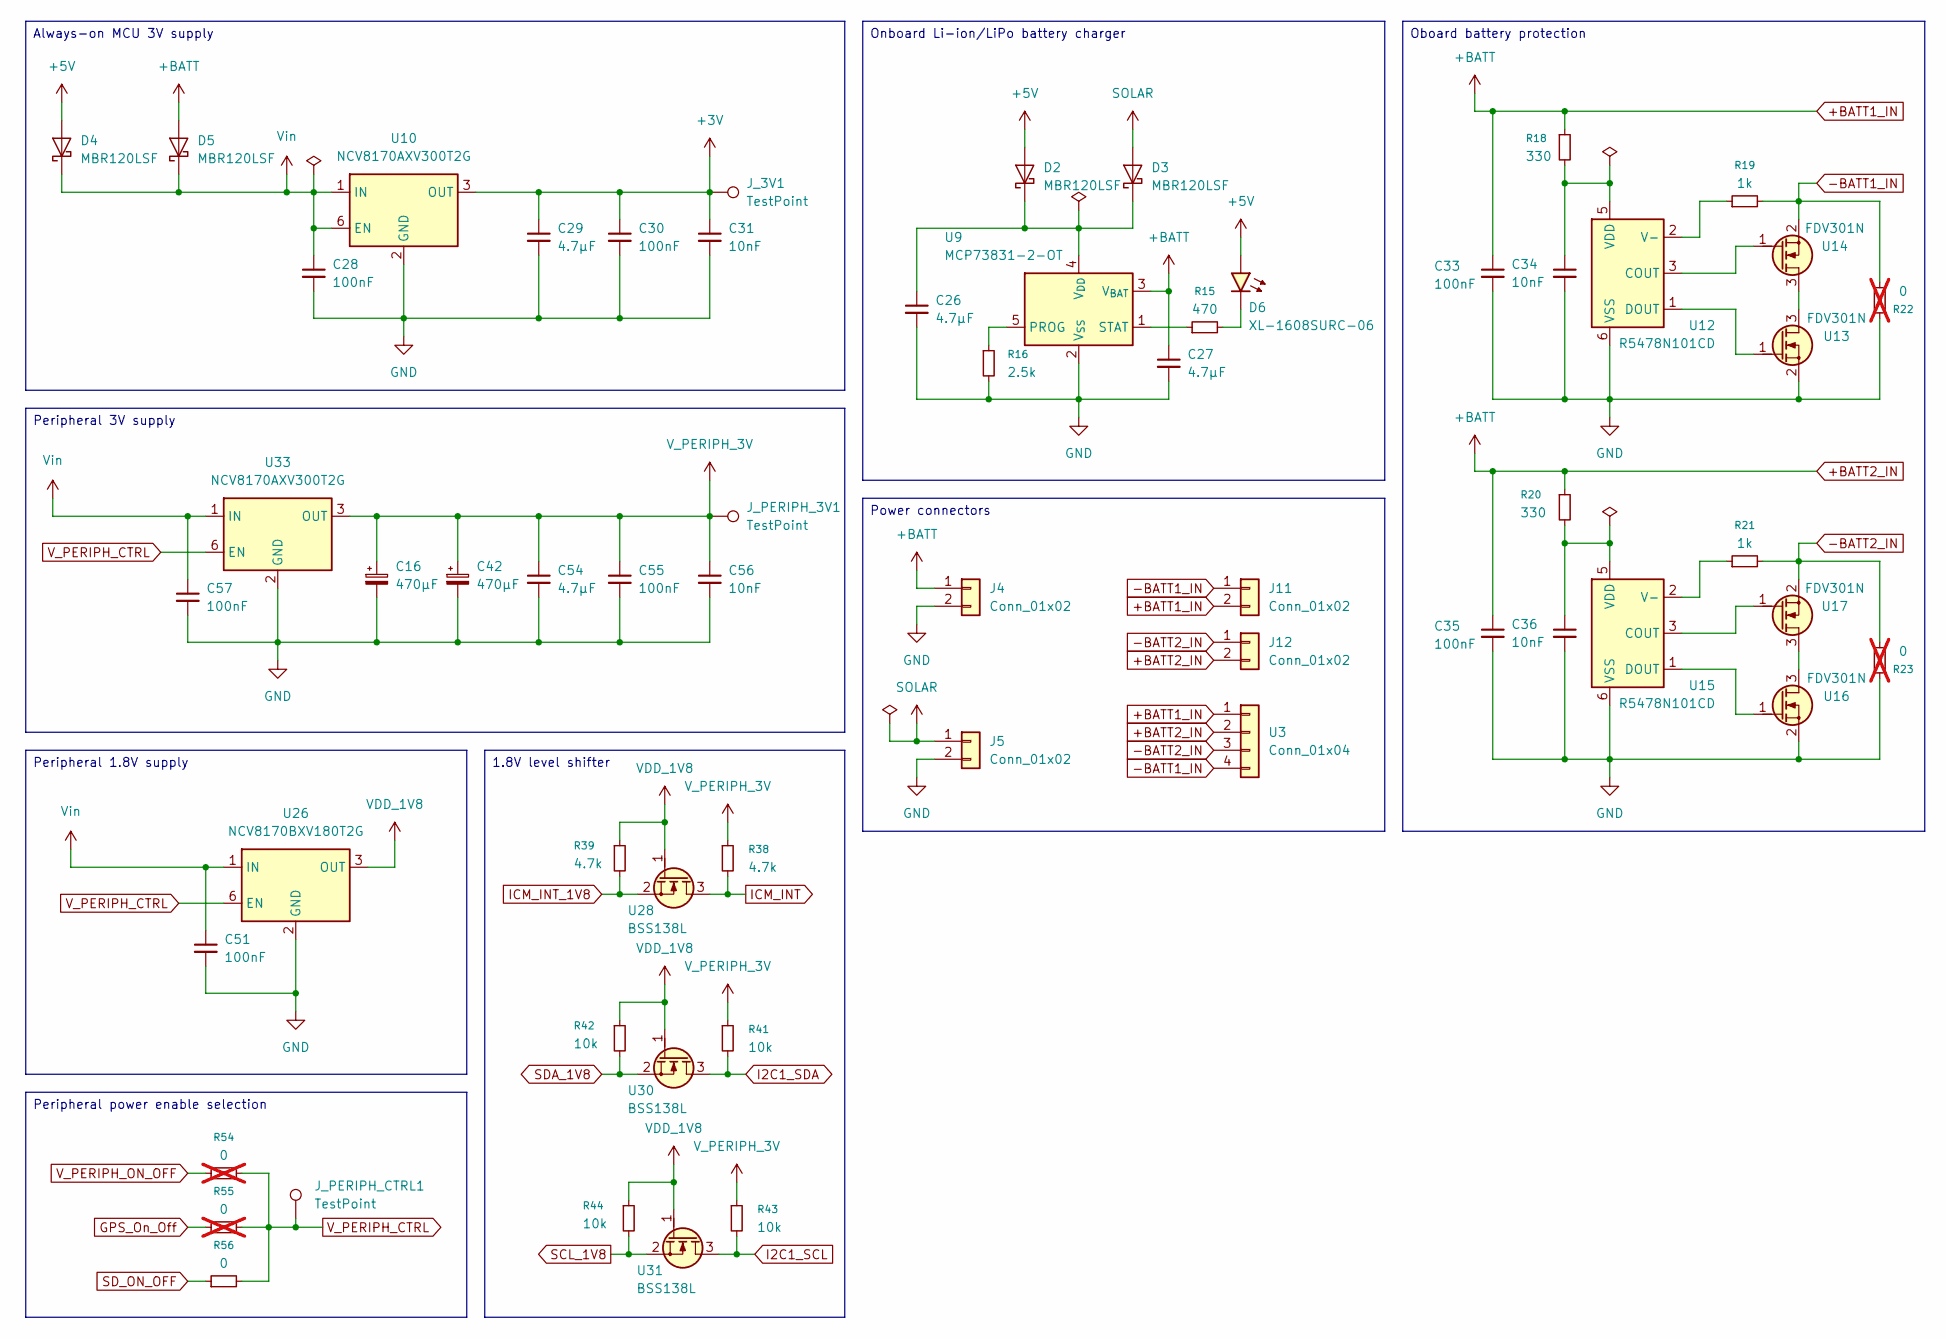
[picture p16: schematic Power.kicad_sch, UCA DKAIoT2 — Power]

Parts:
C16, C42: 470µF; CP_EIA-7343-15_Kemet-W
C26, C27, C29, C54: 4.7µF; C_0402_1005Metric
C28, C30, C33, C35, C51, C55, C57: 100nF; C_0402_1005Metric
C31, C34, C36, C56: 10nF; C_0402_1005Metric
D2, D3, D4, D5: MBR120LSF; D_SOD-123F; LCSC C130880
D6: XL-1608SURC-06; LED_0603_1608Metric; LCSC C965799
J4: Conn_01x02; PinSocket_1x02_P2.54mm_Vertical
J5, J11, J12: Conn_01x02; PinHeader_1x02_P2.54mm_Vertical
J_3V1: TestPoint; TestPoint_Pad_D1.0mm
J_PERIPH_3V1: TestPoint; TestPoint_Pad_D1.0mm
J_PERIPH_CTRL1: TestPoint; TestPoint_Pad_D1.0mm
R15: 470; R_0402_1005Metric
R16: 2.5k; R_0402_1005Metric
R18, R20: 330; R_0402_1005Metric
R19, R21: 1k; R_0402_1005Metric
R22, R23, R54, R55: 0; R_0402_1005Metric; not fitted
R38, R39: 4.7k; R_0402_1005Metric
R41, R42, R43, R44: 10k; R_0402_1005Metric
R56: 0; R_0402_1005Metric
U3: Conn_01x04; BAT-TH_BH-18650-A1BJ034
U9: MCP73831-2-OT; SOT-23-5; LCSC C14879
U10, U33: NCV8170AXV300T2G; SOT-563
U12, U15: R5478N101CD; SOT-23-6
U13, U14, U16, U17: FDV301N; SOT-23
U26: NCV8170BXV180T2G; SOT-563
U28, U30, U31: BSS138L; SOT-23

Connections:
+3V: C29.1, C30.1, C31.1, J_3V1.1 (1_1), U10.3 (OUT); also elsewhere on the board
+5V: D2.2 (A), D4.2 (A), D6.2 (A); also elsewhere on the board
+BATT1_IN: C27.1, C33.1, C35.1, D5.2 (A), J4.1, J11.2, J12.2, R18.1, R20.1, U3.1, U3.2, U9.3 (V_{BAT}); also elsewhere on the board
-BATT1_IN: J11.1, R19.2, R22.2, U3.4, U14.2 (S)
-BATT2_IN: J12.1, R21.2, R23.2, U3.3, U17.2 (S)
GND: C16.2, C26.2, C27.2, C28.2, C29.2, C30.2, C31.2, C33.2, C34.2, C35.2, C36.2, C42.2, C51.2, C54.2, C55.2, C56.2, C57.2, J4.2, J5.2, R16.2, R22.1, R23.1, U9.2 (V_{SS}), U10.2 (GND), U10.5 (GND), U12.6 (VSS), U13.2 (S), U15.6 (VSS), U16.2 (S), U26.2 (GND), U26.5 (GND), U33.2 (GND), U33.5 (GND); also elsewhere on the board
GPS_On_Off: R55.1; also elsewhere on the board
I2C1_SCL: R43.2, U31.3 (D); also elsewhere on the board
I2C1_SDA: R41.2, U30.3 (D); also elsewhere on the board
ICM_INT: R38.2, U28.3 (D); also elsewhere on the board
ICM_INT_1V8: R39.2, U28.2 (S); also elsewhere on the board
unnamed: C26.1, D2.1 (K), D3.1 (K), U9.4 (V_{DD})
unnamed: D6.1 (K), R15.2
unnamed: R16.1, U9.5 (PROG)
unnamed: R15.1, U9.1 (STAT)
unnamed: U12.3 (COUT), U14.1 (G)
unnamed: U12.1 (DOUT), U13.1 (G)
unnamed: R19.1, U12.2 (V-)
unnamed: C34.1, R18.2, U12.5 (VDD)
unnamed: U13.3 (D), U14.3 (D)
unnamed: U15.3 (COUT), U17.1 (G)
unnamed: U15.1 (DOUT), U16.1 (G)
unnamed: R21.1, U15.2 (V-)
unnamed: C36.1, R20.2, U15.5 (VDD)
unnamed: U16.3 (D), U17.3 (D)
SCL_1V8: R44.2, U31.2 (S); also elsewhere on the board
SDA_1V8: R42.2, U30.2 (S); also elsewhere on the board
SD_ON_OFF: R56.1; also elsewhere on the board
SOLAR: D3.2 (A), J5.1; also elsewhere on the board
VDD_1V8: R39.1, R42.1, R44.1, U26.3 (OUT), U28.1 (G), U30.1 (G), U31.1 (G); also elsewhere on the board
V_PERIPH_3V: C16.1, C42.1, C54.1, C55.1, C56.1, J_PERIPH_3V1.1 (1_1), R38.1, R41.1, R43.1, U33.3 (OUT); also elsewhere on the board
V_PERIPH_CTRL: J_PERIPH_CTRL1.1 (1_1), R54.2, R55.2, R56.2, U26.6 (EN), U33.6 (EN)
V_PERIPH_ON_OFF: R54.1; also elsewhere on the board
Vin: C28.1, C51.1, C57.1, D4.1 (K), D5.1 (K), U10.1 (IN), U10.6 (EN), U26.1 (IN), U33.1 (IN); also elsewhere on the board

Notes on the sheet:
Always-on MCU 3V supply
1.8V level shifter
Power connectors
Peripheral 1.8V supply
Onboard Li-ion/LiPo battery charger
Oboard battery protection
Peripheral power enable selection
Peripheral 3V supply

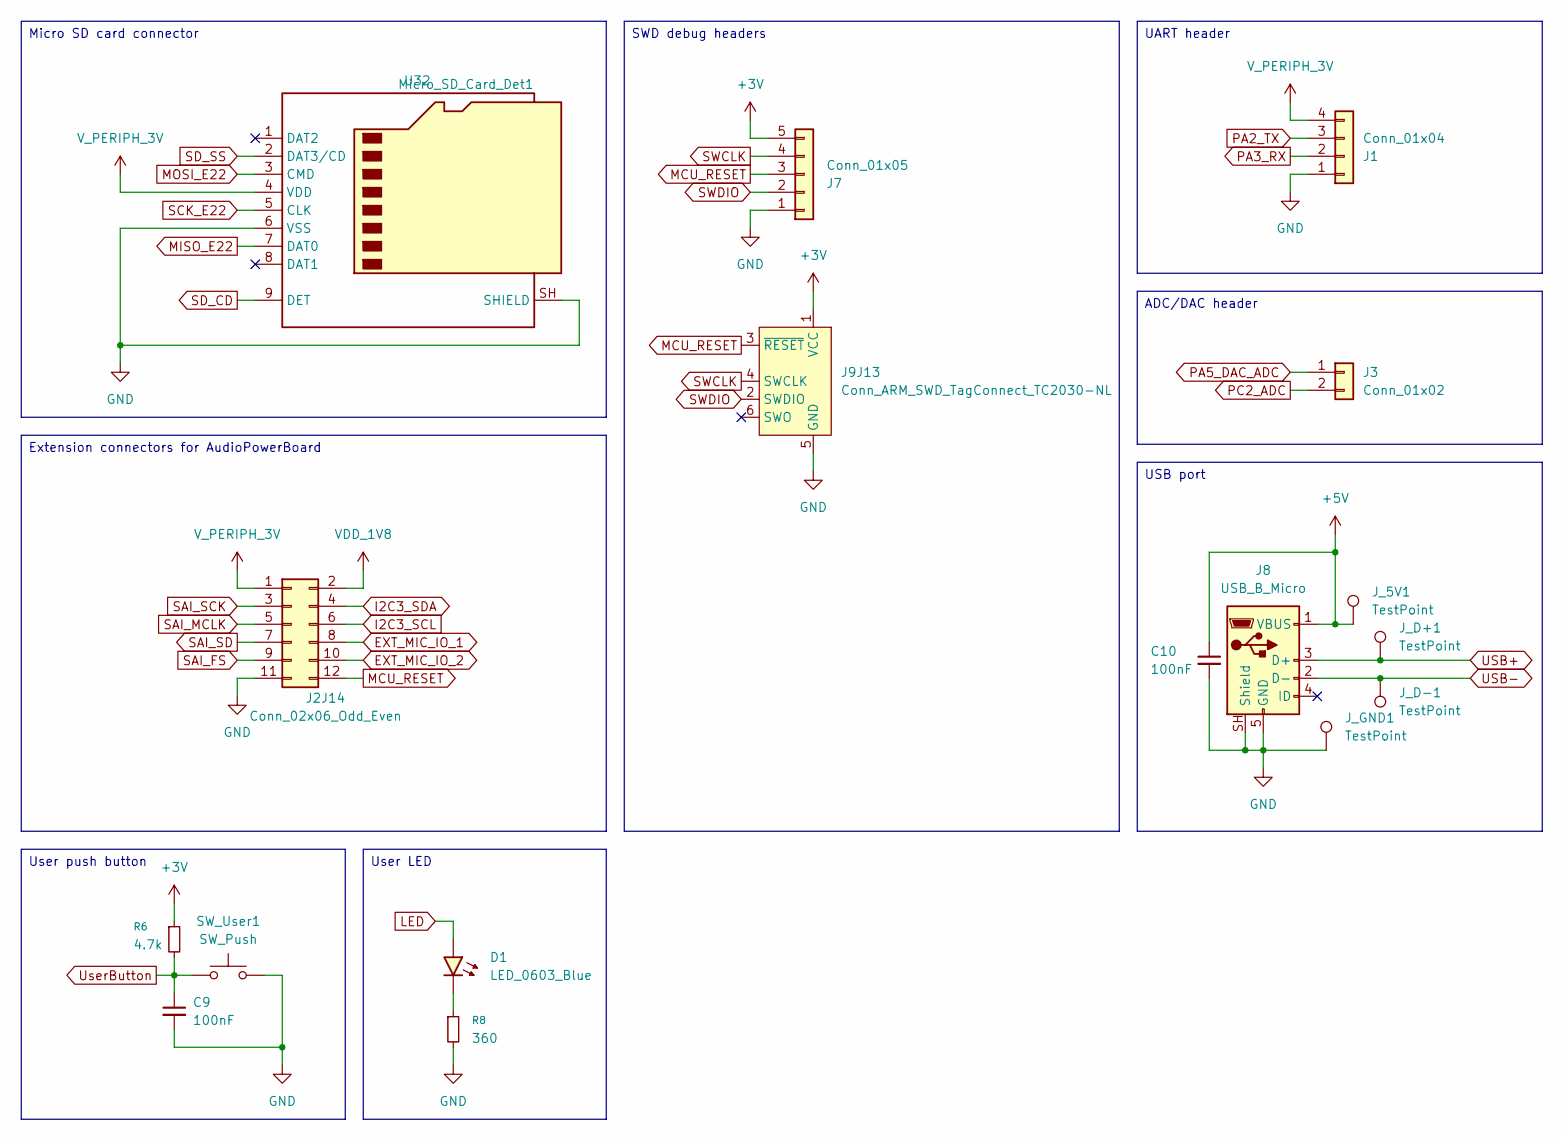
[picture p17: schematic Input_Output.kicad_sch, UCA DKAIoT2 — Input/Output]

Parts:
C9, C10: 100nF; C_0402_1005Metric
D1: LED_0603_Blue; LED_0603_1608Metric
J1: Conn_01x04; PinHeader_1x04_P2.54mm_Vertical
J2J14: Conn_02x06_Odd_Even; PinSocket_2x06_P2.54mm_Vertical
J3: Conn_01x02; PinHeader_1x02_P2.54mm_Vertical
J7: Conn_01x05; PinHeader_1x05_P2.54mm_Vertical
J8: USB_B_Micro; USB_Micro-B_Molex-105017-0001
J9J13: Conn_ARM_SWD_TagConnect_TC2030-NL; Tag-Connect_TC2030-IDC-NL_2x03_P1.27mm_Vertical_TopBottom
J_5V1: TestPoint; TestPoint_Pad_D1.0mm
J_D+1: TestPoint; TestPoint_Pad_D1.0mm
J_D-1: TestPoint; TestPoint_Pad_D1.0mm
J_GND1: TestPoint; TestPoint_Pad_D1.0mm
R6: 4.7k; R_0402_1005Metric
R8: 360; R_0402_1005Metric
SW_User1: SW_Push; Panasonic_EVQPUM_EVQPUD
U32: Micro_SD_Card_Det1; microSD_XKB_XKTF-015-x

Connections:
+3V: J7.5, J9J13.1 (VCC), R6.1; also elsewhere on the board
+5V: C10.1, J8.1 (VBUS), J_5V1.1 (1_1); also elsewhere on the board
EXT_MIC_IO_1: J2J14.8; also elsewhere on the board
EXT_MIC_IO_2: J2J14.10; also elsewhere on the board
GND: C9.2, C10.2, J1.1, J2J14.11, J7.1, J8.5 (GND), J8.SH (Shield), J9J13.5 (GND), J_GND1.1 (1_1), R8.2, SW_User1.2, U32.6 (VSS), U32.SH (SHIELD); also elsewhere on the board
I2C3_SCL: J2J14.6; also elsewhere on the board
I2C3_SDA: J2J14.4; also elsewhere on the board
LED: D1.2 (A); also elsewhere on the board
MCU_RESET: J2J14.12, J7.3, J9J13.3 (~RESET); also elsewhere on the board
MISO_E22: U32.7 (DAT0); also elsewhere on the board
MOSI_E22: U32.3 (CMD); also elsewhere on the board
unnamed: D1.1 (K), R8.1
PA2_TX: J1.3; also elsewhere on the board
PA3_RX: J1.2; also elsewhere on the board
PA5_DAC_ADC: J3.1; also elsewhere on the board
PC2_ADC: J3.2; also elsewhere on the board
SAI_FS: J2J14.9; also elsewhere on the board
SAI_MCLK: J2J14.5; also elsewhere on the board
SAI_SCK: J2J14.3; also elsewhere on the board
SAI_SD: J2J14.7; also elsewhere on the board
SCK_E22: U32.5 (CLK); also elsewhere on the board
SD_CD: U32.9 (DET); also elsewhere on the board
SD_SS: U32.2 (DAT3/CD); also elsewhere on the board
SWCLK: J7.4, J9J13.4 (SWCLK); also elsewhere on the board
SWDIO: J7.2, J9J13.2 (SWDIO); also elsewhere on the board
USB+: J8.3 (D+), J_D+1.1 (1_1); also elsewhere on the board
USB-: J8.2 (D-), J_D-1.1 (1_1); also elsewhere on the board
UserButton: C9.1, R6.2, SW_User1.1; also elsewhere on the board
VDD_1V8: J2J14.2; also elsewhere on the board
V_PERIPH_3V: J1.4, J2J14.1, U32.4 (VDD); also elsewhere on the board

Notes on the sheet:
USB port
User push button
SWD debug headers
UART header
Extension connectors for AudioPowerBoard
Micro SD card connector
ADC/DAC header
User LED

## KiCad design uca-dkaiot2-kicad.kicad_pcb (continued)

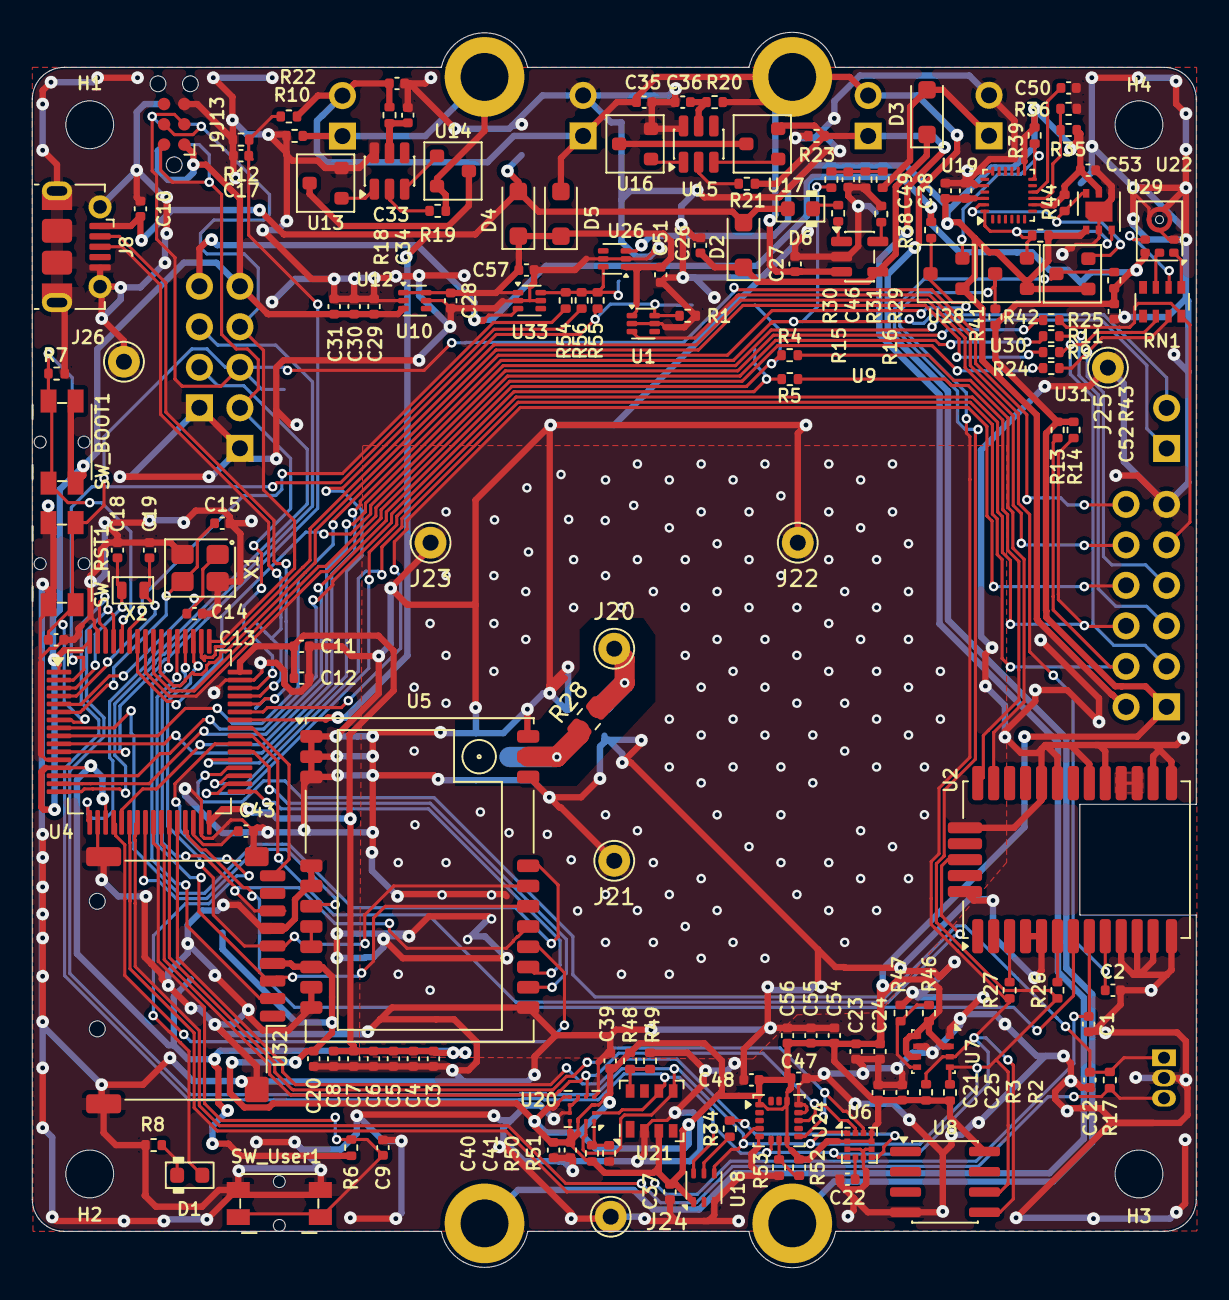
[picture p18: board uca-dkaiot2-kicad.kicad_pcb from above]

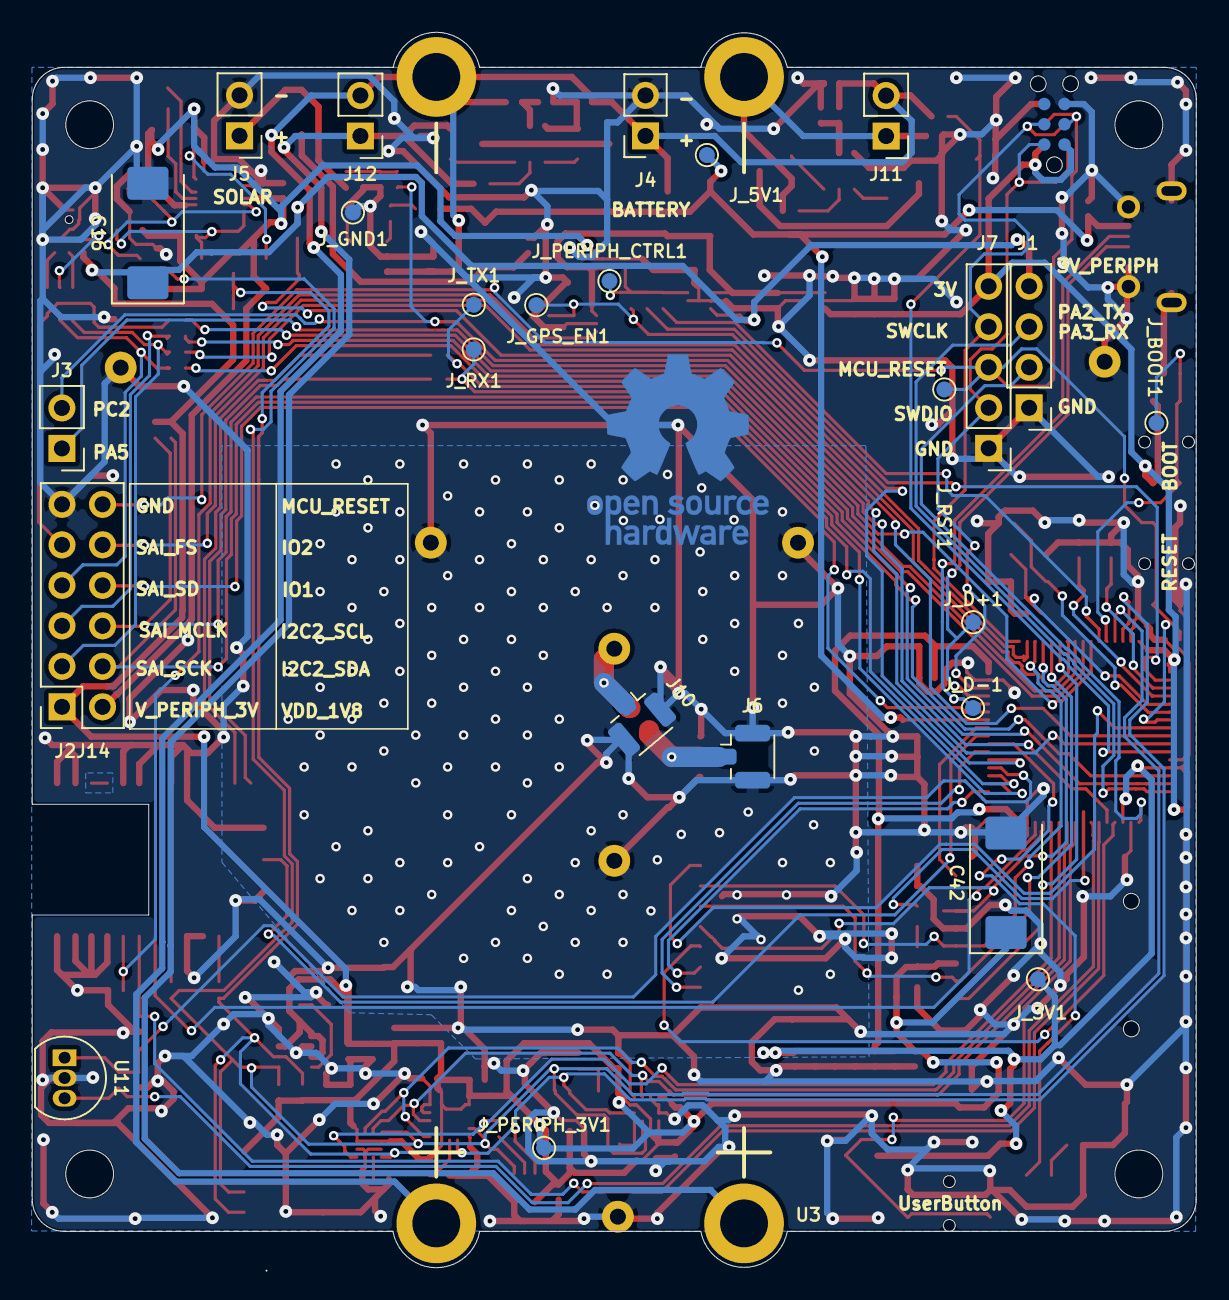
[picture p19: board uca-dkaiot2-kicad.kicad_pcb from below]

Board: 2 copper layers, 73.0 x 77.5 mm, 184 parts (27 on the bottom side), 106 nets.

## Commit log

2026-05-26 WIP: KiCad project
    [LoRa.kicad_sch, MCU.kicad_sch, Power.kicad_sch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]
2026-05-27 Add footprint library for Sensirion DFN-6 2.44x2.44mm P0.8mm
2026-05-27 Continue filling schematics
    [Input_Output.kicad_sch, LoRa.kicad_sch, MCU.kicad_sch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]
2026-05-27 libraries/Onsemi_NCV8170.kicad_sym: fix part number in symbol for B variant
2026-05-28 libraries: update footprint filter for Kionix_KX023, Onsemi_NCV8170 and Sensirion_SGP30
2026-05-28 Add E22-400M22S footprint
2026-05-28 Add footprints microSD_XKB_XKTF-015-x BAT-TH_BH-18650-A1BJ034
2026-05-28 Finalize schematics as AIoT2-rev003-May1326
    [Input_Output.kicad_sch, LoRa.kicad_sch, MCU.kicad_sch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]
2026-05-28 Schematics Ambient variant with unneeded sensors DNP
    [Input_Output.kicad_sch, LoRa.kicad_sch, MCU.kicad_sch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]
2026-05-29 footprint: microSD_XKB_XKTF-015-x pin 10 → SH
2026-05-29 Add footprint for HP203B
2026-05-29 symbol: SGP30: fix center pad pin number
2026-05-29 PCB component placement according to AIoT2
    [Input_Output.kicad_sch, LoRa.kicad_sch, Sensors.kicad_sch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]
2026-06-01 pcb: 2-layer stackup
    [uca-dkaiot2-kicad.kicad_pcb]
2026-06-01 pcb: remove original AIoT2 design
    [uca-dkaiot2-kicad.kicad_pcb]
2026-06-01 pcb: start 2-layer routing
    [Input_Output.kicad_sch, Power.kicad_sch, uca-dkaiot2-kicad.kicad_pcb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]
2026-06-02 pcb: continue routing
    [uca-dkaiot2-kicad.kicad_pcb]
2026-06-04 schematics: add some DNP for Ambient variant
    [Input_Output.kicad_sch, Power.kicad_sch, Sensors.kicad_sch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]
2026-06-04 pcb: silkscreen placement and some cleanup
    [uca-dkaiot2-kicad.kicad_pcb]
2026-06-04 pcb: disable Pad to Silkscreen clearance rule
2026-06-04 pcb: 1 minimum spoke for thermal relief, silkscreen clearance reduced to 0.05, add some DRC exclusions
2026-06-04 pcb: pins for antenna, silkscreen…
    [LoRa.kicad_sch, uca-dkaiot2-kicad.kicad_pcb]
2026-06-04 pcb: via stitching
    [uca-dkaiot2-kicad.kicad_pcb]
2026-06-04 pcb: some fixes
    [uca-dkaiot2-kicad.kicad_pcb]
2026-06-05 Add OSHW logo
    [uca-dkaiot2-kicad.kicad_pcb, uca-dkaiot2-kicad.kicad_sch]
2026-06-05 Add pdf/ gerbers/
    [Input_Output.kicad_sch, LoRa.kicad_sch, MCU.kicad_sch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]
2026-06-05 OSHW logo tied to ground net
    [LoRa.kicad_sch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]
2026-06-14 v0.2: fix Ebyte E22-900M22S pinout
    [Input_Output.kicad_sch, LoRa.kicad_sch, MCU.kicad_sch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]
2026-06-14 pcb: fix revision number text
    [uca-dkaiot2-kicad-B_Cu.gbl, uca-dkaiot2-kicad-B_Mask.gbs, uca-dkaiot2-kicad-B_Paste.gbp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]
